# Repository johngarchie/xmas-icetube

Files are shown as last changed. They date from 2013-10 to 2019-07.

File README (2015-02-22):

##########################
## XMAS-ICETUBE PROJECT ##
##########################

Several years ago, my father gave me an Adafruit Ice Tube Clock kit as
a Christmas gift.  As an excuse to learn AVR programming, I started
playing with the firmware.  Eventually, none of the original Adafruit
code remained, and the result was a feature-rich reimplementation of
the Adafruit firmware.

Once the firmware was mature, I decided to revise the hardware design
to support many of the hacks and mods described on the Adafruit
forums.  With the help of other clock hackers, especially Phil DeGruy
and Russell Walker, the xmas-icetube hardware revision became a reality.

Today, the xmas-icetube firmware still runs on the Adafruit Ice Tube
Clock v1.1 as well as the xmas-icetube hardware revision.  For more
information on the firmware and hardware portions of this project,
please check out the firmware/README and hardware/README files.

Finally, although the xmas-icetube project is named after Christmas,
it is designed for use year-round.  The name is also a reference to
Christmas as a cultural holiday--not a religious one.  I sincerely
hope this project is compatible with all religions.

  John Archie <www.jarchie.com/email>
  April 2, 2014

###################
## USER FEEDBACK ##
###################

Below is a selection of comments posted on the Adafruit Clocks
forum.  They are listed in reverse chronological order.  And to
everyone quoted below:  Thank you all for the kind words!

  "[The xmas firmware] just worked from the beginning...
   Great documentation!"
     --MikeHg
       http://forums.adafruit.com/viewtopic.php?p=324261#p324261

  "Every mod works beautifully...  The code truly is clever...
   [John's] code is so clean that it's easy to add things."
     --rcb
       http://forums.adafruit.com/viewtopic.php?p=244224#p244224

  "This firmware is really cool. I highly recommend anyone with an
   ATmega328p lying around to program it with this firmware and use
   it instead of the one that comes with the kit."
     --motocoder
       http://forums.adafruit.com/viewtopic.php?p=243916#p243916

  "[John] has done a lot of nice work and added a lot of features.
   I can recommend his firmware as an upgrade..."
     --adafruit_support_bill,
       http://forums.adafruit.com/viewtopic.php?p=211476#p211476

  "...I LOVE your firmware, and for about 2 weeks I was still
   finding new options and features in the menu."
     --wildtang3nt
       http://forums.adafruit.com/viewtopic.php?p=204665#p204665

  "+10 for John's firmware!  Please do not let the 'xmas' name sway
   you from giving it a try. It's the most feature complete Ice-Tube
   Clock firmware to date."
     --revnull
       http://forums.adafruit.com/viewtopic.php?p=180609#p180609

##############
## FEATURES ##
##############

The xmas-icetube firmware offers the following improvements over
the official Adafruit firmware:

  - GPS synchronized timekeeping*
  - fully automatic compensation for clock drift
  - animated display transitions
  - multiple time and date formats
  - DST support (USA, EU, or manual)
  - pulsing display brightness during alarm and snooze
  - three alarm times for selectable days of the week
  - functional alarm during power outage**
  - finely adjustable alarm volume (from 0 to 10)
  - progressive alarm option (gradually increasing volume)
  - adjustable snooze duration
  - selectable alarm sound (high frequency beeps, low frequency beeps,
    high frequency three beep pulse, low frequency three beep pulse,
    Merry Christmas, Big Ben, Reveille, or For He's a Jolly Good Fellow)
  - 4-fold improvement in battery life
  - no beeping or time loss after external power failure
  - low battery warning before battery failure
  - per-digit brightness adjustment for uneven displays
  - larger range for user-configured display brightness
  - optionally disable display during specified time periods

*  An external GPS module, such as the Adafruit Ultimate GPS, is
   necessary to support GPS synchronized timekeeping.

** Without external power, the alarm sounds with loud high frequency
   beeps.  The only way to turn the alarm on or off is with the alarm
   switch.  Snooze is not supported.

The following additional features are supported on the xmas-icetube
hardware revision, but the Adafruit Ice Tube Clock v1.1 can be
modified to support any or all of the following as well:

  - automatic brightness control by ambient light
  - optionally disable display at night (when dark)
  - 25-fold improvement in battery life
  - highly accurate temperature compensated timekeeping
  - IV-18 tube driven to specifications (providing more even
    display illumination and preventing cathode poisoning)

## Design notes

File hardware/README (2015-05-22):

####################################
## XMAS-ICETUBE HARDWARE REVISION ##
####################################

The xmas-icetube hardware revision is a revision of the Adafruit Ice Tube
Clock v1.1 hardware design to support many of the hacks and mods that have
been posted to the Adafruit forums over the years.  The original circuit
board has been extensively revised, but the case and overall look of the
clock is nearly identical to the original design.

The xmas-icetube hardware revision is discussed in the following thread:

    http://forums.adafruit.com/viewtopic.php?t=43836

##############
## FEATURES ##
##############

The xmas-icetube revision has the following improvements over the original
Adafruit design.  Although all of these features are incorporated into the
xmas-icetube board, many of the links given are oriented toward modifying
the original Adafruit clock to include the corresponding features.  Those
discussions are still relevant to the xmas-icetube revision, however.

* IV-18 tube driven to specifications:  The Adafruit design runs the IV-18
  in a way that results in inconsistent illumination across the display,
  and on some tubes, the effect is quite noticeable.  The original IV-18
  drive also accelerated the process of cathode poisoning.  Driving the
  IV-18 as the designers intended ensures uniform illumination and makes
  the tube less prone to cathode poisoning.

  http://forums.adafruit.com/viewtopic.php?t=23586
  http://forums.adafruit.com/viewtopic.php?t=41811

* Automatic dimming:  A photoresistor allows automatic dimming as
  appropriate for the ambient lighting.  The Adafruit design does,
  however, have an expansion area that can also be used to this end.

  http://forums.adafruit.com/viewtopic.php?t=12932

* 25-fold reduction in sleep current:  Unless the clock is without power
  for over a year, the battery should never need replacement.

  http://forums.adafruit.com/viewtopic.php?t=36697  
  http://forums.adafruit.com/viewtopic.php?p=219736#p219736

* Temperature compensated timekeeping:  A DS18B20 temperature sensor next
  to the clock crystal allows the software to compensate for temperature-
  related timekeeping error.  When combined with software-based drift
  correction, the resulting accuracy should be comparable to a temperature
  compensated quartz oscillator.

  http://forums.adafruit.com/viewtopic.php?t=43998
  http://forums.adafruit.com/viewtopic.php?f=41&t=12720

* GPS solder points:  Through-hole solder points allow easier installation
  of an external GPS unit for time synchronization.

  http://forums.adafruit.com/viewtopic.php?t=36873
  http://learn.adafruit.com/ice-tube-clock-kit/mods

  Alternatively, these solder points may also be used for installing a
  dedicated temperature compensated crystal oscillator instead of the
  DS18B20 temperature sensor above.

  http://forums.adafruit.com/viewtopic.php?&t=14941

* Robust in-system programming:  The clock may be programmed regardless of
  whether the display and side board are installed.  I recommend powering
  the clock with external power during programming, but a programming
  jumper provides a way to force the clock into sleep mode to ensure minimal
  power consumption if powered by the programmer instead.  I recommend
  using the jumper if using the AVR Dragon programmer, as the Dragon can
  barely provide enough power for programming alone.  But the jumper is
  unnecessary for most programmers including the Adafruit USBtinyISP.

  http://forums.adafruit.com/viewtopic.php?t=41975

* Robust microcontroller environment:  The microcontroller now has a
  decoupling capacitor and 10K pull-up on the reset pin.  These
  components make the clock less sensitive to electrical noise and
  ensure reliable operation.

Finally, although the xmas-icetube firmware is compatible with *both* the
original Adafruit clock and the xmas-icetube hardware revision, the
xmas-icetube revision is not compatible with firmwares developed
specifically for the Adafruit clock.

##########################
## COLLECTING THE PARTS ##
##########################

The current versions of the xmas-icetube custom parts are:

  - main board   (Rev. D)
  - side board   (Rev. C)
  - acrylic case (Rev. A)

I ordered my circuit boards from OSH Park and have shared those uploads
in case others would like to do the same:

    http://www.oshpark.com/shared_projects/6xAVpeHb
    http://www.oshpark.com/shared_projects/PiRXWH3F

I ordered the 3mm clear acrylic parts from Ponoko and have also shared
that design:

    http://www.ponoko.com/showroom/jarchie

For those in Europe, Formulor (http://www.formulor.de/) is an alternative
source for the acrylic parts.  Formulor is a Ponoko partner and accepts
the same SVG design format.  Many thanks to Tobias Scharmann for
suggesting this service.

See the enclosed bill of materials (BOM.csv) for a complete parts list,
including manufacturers, suppliers, and part numbers.

########################
## BUILDING THE CLOCK ##
########################

For aesthetic reasons, the xmas-icetube design uses TO-92 packages for the
voltage regulators, so their ability to burn off excess voltage is limited.
The 9VDC input should stay below 10v at 120 mA to be on the safe side:  A
standard regulated switching-type 9v adapter should work fine, but I
recommend against using an older, unregulated, transformer-type wall wort.

Alternatively, the board will accommodate regulators in TO-220 packages,
even though the silkscreen shows TO-92 packages.  The holes are a bit small
for TO-220s, so it might be necessary to file down the TO-220 leads to make
them narrower, but those packages will work with a bit of extra effort.
Although, I do prefer the TO-92s, TO-220s would look okay--just a bit bulky.

When assembling the parts, I suggest building the circuit incrementally and
testing each section after it is built.  See the Eagle schematics for the
parts in each section.

1.  Solder the "5V Power Supply" parts.  Connect the 9v adaptor and verify
    that the power supply outputs 5v; disconnect and proceed.

2.  Solder the "Temperature Sensor" parts.  (It's easier to solder R9
    before inserting the microcontroller into its socket.)

3.  Solder the "Microcontroller", "ISP Header", "Battery Sensor", and
    "Speaker" parts.  Program the ATmega328P (see the firmware/README file
    for details).  When powered with the AC adaptor, the speaker should
    beep when powered for the first time.  Keep the AC adaptor connected
    for at least ten seconds after hearing the beep.

    If the speaker does not beep, ensure the programming jumper has been
    removed and that the ATmega328P is properly programmed.  If the speaker
    beeps repeatedly at 8 second intervals, the problem is most likely with
    the crystal oscillator.  If the oscillator parts and connections are
    good, cleaning excess rosin from the board with a toothbrush and
    rubbing alcohol might fix the problem, but make sure the board is
    completely dry before powering it again.

4.  Solder the "5VAC Cathode/Filament Supply" parts.  Measure the AC voltage
    between the two push-pull outputs (AC1 and AC2).  The push-pulls should
    provide high frequency, square wave, alternating current, which most
    multimeters cannot measure accurately.  Without a load, the LM317 will not
    effectively regulate voltage anyway, so multimeter accuracy does not
    matter.  So ensure that AC1 and AC2 are providing alternating current,
    but the amount of voltage measured is not important.

5.  Solder the "Tube 30-60VDC Boost Supply" parts.  Note that the joined
    leads of Q2 should be oriented toward C6.  Connect the 9v adaptor and
    verify that the boost circuit indeed provides 50-60 volts.

6.  Solder the "VFD Anode/Segment Controller" and "VFD Tube / Side PCB"
    parts.  Attach the side board to the main board, connect the 9v
    adaptor, and verify that the VFD display is functional.

7.  Solder the "Buttons and Alarm Switch" parts.  Connect the 9v adaptor
    and verify that the buttons and alarm switch function properly.

8.  Solder the "Battery Backup" parts and insert a battery, but before
    soldiering the battery case, apply a small amount of solder to the
    battery's ground connection (large square pad).  A small amount of
    solder will add height to the square pad connection and ensure a good
    connection between the battery and ground.

    Connect the 9v adaptor, set the time, disconnect the 9v adaptor for ten
    minutes, connect it again, and verify that the clock kept the correct
    time.  Because the clock is extremely power-efficient during sleep, the
    capacitors store enough charge to keep the clock running for 3-5
    minutes.  Leaving the clock unplugged for ten minutes ensures that the
    backup battery is actually in use.

9.  Solder the "Light Sensor" parts.  So the clock can accurately gauge
    ambient lighting, install the photoresistor such that it points towards
    the front of the clock and away from the tube.  Connect the 9v adaptor,
    and using a flashlight, lamp, or similar, verify that the clock
    responds to changes in ambient light.

10. Assemble the acrylic case and enjoy!

##############################
## EDITING THE DESIGN FILES ##
##############################

The board revisions can be opened and and modified with Eagle,
which is available from CadSoft:

    http://www.cadsoftusa.com/

The case revision may be viewed and modified in Inkscape:

    http://inkscape.org/

######################
## ACKNOWLEDGEMENTS ##
######################

The Adafruit Ice Tube Clock board was loosely based on the inGrid
IV-18 clock by Riad S. Wahby.  My xmas-icetube board revision is based
on the Adafruit Ice Tube Clock board by Lady Ada.

The clock case was originally designed by Amanda Wozniak (w0z), and I have
only made minor adjustments to her design.  Adafruit forum user Daygecko
also deserves credit for finding clear machine nuts and bolts from
McMaster-Carr, which give the assembled case a cleaner look.

Phil DeGruy (PhilD13) reviewed my initial design and suggested several
components; the ZVN2110A and ZVP2001A MOSFETs in particular were
especially useful for generating AC for the IV-18 filament.  Phil
also found many alternative parts for the bill of materials which cost
less than my original selections.

I also had fruitful discussions with both Phil DeGruy and Russell Walker
(Russell27), mostly  in regard to properly driving the IV-18 tube.  Phil
and Russell built their own xmas-icetube clocks and provided useful
feedback on the overall design.

Because I am inexperienced in electronics design, I must add the following
disclaimer:  Those cited in this section cannot be faulted for any bugs in
the xmas-icetube hardware revision.

#############
## LICENSE ##
#############

The xmas-icetube hardware revision may be used under the Attribution-
ShareAlike 3.0 (CC BY-SA 3.0), available from Creative Commons:

    http://creativecommons.org/licenses/by-sa/3.0/

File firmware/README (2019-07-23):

###########################
## XMAS-ICETUBE FIRMWARE ##
###########################

The xmas-icetube firmware is a complete reimplementation of the Adafruit
Ice Tube Clock firmware and runs on *both* the Adafruit Ice Tube Clock v1.1
and the xmas-icetube hardware revision.  Since most users will be using the
xmas-icetube firmware on the Adafruit Ice Tube Clock v1.1, the default
firmware configuration is set for the Adafruit clock.

The xmas-icetube firmware is discussed in the following Adafruit thread,
which is a good place to post questions and comments:

  http://forums.adafruit.com/viewtopic.php?f=41&t=34924

##############
## FEATURES ##
##############

Many of the features in the xmas-icetube firmware were first implemented in
other firmware projects; see the CREDITS file for details.  This firmware
boasts the following improvements over the official Adafruit firmware:

  - animated display transitions
  - multiple time and date formats
  - optionally pulse display during alarm and snooze
  - three alarm times for selectable days of the week
  - functional alarm during power outage
  - adjustable alarm volume (from 0 to 10)
  - progressive alarm option (gradually increasing volume)
  - selectable alarm sound (high frequency beeps, low frequency beeps,
    high frequency three beep pulse, low frequency three beep pulse,
    Merry Christmas, Big Ben, Reveille, or For He's a Jolly Good Fellow)
  - adjustable snooze duration
  - DST support (USA, EU, or manual)
  - fully automatic correction for time drift
  - time-from-GPS support*
  - temperature compensated timekeeping*
  - no beeping or time loss after external power failure
  - 4-fold or 25-fold* increase in backup battery life
  - low battery warning before battery failure
  - larger range for user-configured display brightness
  - per-digit brightness adjustment for uneven displays
  - automatic brightness control by ambient light*
  - optionally disable display during specified time periods
  - optionally disable display at night (when dark)*
  - IV-18 VFD tube driven to specifications*

*  For the Adafruit Ice Tube Clock v1.1, these hacks require hardware
   modification and support must be enabled by uncommenting macros in
   config.h.  See the HACKS AND MODS section of this file as well as the
   comments in config.h for more information.

For clock hackers, this firmware has

    (1) compatibility with the ATmega328p,
    (2) a pseudo object-oriented design,
    (3) good source code documentation, and
    (4) display/menus by finite state machine.

##################
## INSTALLATION ##
##################

Installation requires GNU Make, avr-libc, avr-gcc, and avrdude; the
instructions below presume proficiency with these tools.

This firmware requires the ATmega328p, not the ATmega168v included with
the Adafruit kit.  Due to the many features, xmas-icetube currently
requires around 30 kB of program memory, but the ATmega168v only has
16 kB.  The ATmega328p also supports Atmel picoPower features that are
used to extend battery life by 4-fold (and 25-fold with a minor hardware
modification).  The ATmega168v does not support picoPower.

Note that if your ATmega328p has an Arduino bootloader installed, it
will not work without reconfiguration.  See the TROUBLESHOOTING section
for reconfiguration instructions.

To program the chip, any avrdude-compatible ISP programmer should work,
but programming has been tested with the Adafruit USBtinyISP, the Atmel
AVR Dragon, and an Arduino programed with the ArduinoISP sketch.

Compilation and installation has been tested under

    (a) Ubuntu Linux 12.04 with the avr-gcc and avrdude packages,
    (b) MacOS 10.14.5 with CrossPack for AVR Development, and
    (c) Windows 10 with WinAVR and Cygwin's perl and bash packages.

To compile and install this firmware, first configure compile-time
options by editing the Makefile and config.h.  Then build and install the
project using the included Makefile:

(1) Edit the Configuration Variables

    First, review the macro definitions in config.h, changing definitions
    as needed to enable support for various hardware hacks.  The default
    values in config.h are suitable for the Adafruit Ice Tube Clock v1.1
    and includes support for the autodimmer and GPS mods.  For the
    xmas-icetube hardware revision, it may be more convenient to copy the
    config.h file from the hardware directory and edit that as desired:

	% cp ../hardware/config.h config.h

    Next, review the Makefile to ensure that configuration variables are
    reasonable given your hardware.  In particular, AVRISP and AVRDUDEOPT
    seem most likely to require attention.

(2) Compile the Firmware

    Build icetube_fuse.hex, icetube_flash.hex, icetube_eeprom.hex, and
    icetube_lock.hex which contain the fuse bits, program memory (flash),
    EEPROM data, and lock bits:

	% make

(3) Connect the Programmer

    Ensure the clock has an ATmega328p installed and not an ATmega168v.
    Unplug and disassemble the clock.  Remove the side PCB with VFD tube.
    Make sure that the AVR programmer will not provide power to the clock.
    (For the Adafruit USBtinyISP, this means ensuring that the
    power jumper is not installed.)  Connect the AVR programmer to the
    clock's ISP header, ensuring that pin one on the cable and the marked
    pin on the clock's ISP header match.  Finally, power the clock board
    with the external power adaptor.

(4) Install the Firmware

    Install this firmware to an ATmega328p by setting the fuse bits,
    writing the flash program, writing the EEPROM data, and setting the
    lock bits:

        % make install-all

    Alternatively, this firmware may be installed or upgraded in separate
    steps.  If you wish not to set lockbits or not to overwrite the
    EEPROM (clock settings), simply skip those commands below.

        % make install-fuse
        % make install-flash
        % make install-eeprom
        % make install-lock

(5) Verify Successful Programming (Optional, but Recommended)

    To ensure that the chip has been successfully programmed, one may
    check the chip data against what should have been installed in the
    previous step:

        % make verify-all

    One may also verify the individual sections of programmed memory.
    The following commands are equivalent to "make verify-all":

        % make verify-fuse
        % make verify-flash
        % make verify-eeprom
        % make verify-lock

#####################
## USING THE CLOCK ##
#####################

The USAGE file contains an overview of how to use the clock.

####################
## HACKS AND MODS ##
####################

Development of the various hacks and mods supported by this firmware
have been discussed extensively on the Adafruit discussion board.
Options requiring hardware changes can be enabled by uncommenting
macros in the config.h file.  Comments in the config.h describe each
optional feature in detail.

:: Automatic Display Dimming ::
http://forums.adafruit.com/viewtopic.php?f=41&t=12932
http://forums.adafruit.com/viewtopic.php?p=219736#p219736

:: Temperature Compensated Timekeeping ::
http://forums.adafruit.com/viewtopic.php?f=41&t=14941
http://forums.adafruit.com/viewtopic.php?f=41&t=43998

:: GPS Timekeeping ::
http://forums.adafruit.com/viewtopic.php?f=41&t=36873
http://learn.adafruit.com/ice-tube-clock-kit/mods
http://forums.adafruit.com/viewtopic.php?f=41&t=32660

:: Extended Battery Life ::
http://forums.adafruit.com/viewtopic.php?f=41&t=36697

:: IV-18 To-Spec Hack ::
http://forums.adafruit.com/viewtopic.php?f=41&t=41811

:: Reliably Sleeping During Power Failure ::
http://forums.adafruit.com/viewtopic.php?f=41&t=22515

:: Automatic Drift Correction ::
http://forums.adafruit.com/viewtopic.php?f=41&t=12720

:: Per-Digit Brightness Adjustment ::
http://forums.adafruit.com/viewtopic.php?f=41&t=23586

#####################
## TROUBLESHOOTING ##
#####################

:: General Troubleshooting ::

For many hardware issues, the Adafruit FAQs are quite helpful:

  http://forums.adafruit.com/viewtopic.php?f=41&t=27032
  http://learn.adafruit.com/ice-tube-clock-kit/faq

The Adafruit Clocks forums is an excellent place to ask for help:

  http://forums.adafruit.com/viewforum.php?f=41

:: Reset and Diagnostic Messages ::

After a reset, the microcontroller will examine MCUSR (microcontroller
unit status register) to determine the reason for the reset, and the
display will alternate between the restored time and a message showing
the cause of the reset.  Reset messages can be dismissed by setting
the time, as the time is usually wrong after a reset.

  "bod rset" (brown out detection reset):  The clock was reset due to
      insufficient voltage.  This usually happens when power is lost
      and the backup battery is nearly dead.

  "pin rset" (external reset):  The clock was reset by an external
      signal to the microcontroller reset pin (pin 1).  Programming
      the clock through the ISP header will trigger an external reset.
      Accidently shorting the reset pin to ground will do the same.
      This message used to read "ext rset", but the "x" looked more
      like an "H".

  "pwr rset" (power reset):  The clock started up after a complete
      power loss.  This usually happens if the clock loses external
      with without a backup battery or with a completely dead backup
      battery.

  "wdt rset" (watchdog timer reset):  During normal operation the
      clock will periodically reset the watchdog timer.  If this
      timer expires, the clock is behaving abnormally and will reset
      itself in an attempt to fix the problem.  Usually watchdog timer
      resets are caused by problems with the crystal oscillator; see
      the troubleshooting entry on crystal oscillator problems.

  "oth rset" (other reset):  If no flags were set in MCUSR to indicate
      the cause of the reset, the display will flash "oth rest".  In
      theory, this should never happen.

The clock might also flash one of the following status messages:

  "bad batt" (low battery warning):  The microcontroller checks
      the system voltage whenever the clock sleeps for more than ten
      minutes.  When the battery is low, the display will flash
      "bad batt" after the clock wakes, and the message can be
      dismissed by pressing any button.

  "gps lost" (GPS signal lost; only applies if GPS_TIMEKEEPING was
      defined in config.h):  The clock is receiving data from the GPS,
      but the GPS has been unable to acquire a signal for at least
      three minutes.

  "temp err" (temperature sensor error; only applies if
      TEMPERATURE_SENSOR was defined in config.h):  If the
      microcontroller is unable to communicate with the temperature
      sensor, the display will flash "temp err".

:: Programming Fails with an Arduino Chip ::

The Arduino Uno chip is an ATmega328p, but will not work in an Ice
Tube Clock without reconfiguration.  Arduino chips have their fuse
settings configured to use an external 16 MHz oscillator for the
system clock.  The Ice Tube Clock does not provide a suitable external
oscillator, and without an external oscillator, an Arduino chip will
not function--not even to be reconfigured.

To provide an external oscillator for reconfiguration, insert the
Arduino chip into an Arduino board.  Next, connect a programmer to the
ISP on the Arduino board and reprogram the fuses with the xmas-icetube
Makefile:  "make install-fuse".  The ATmega328p's fuse settings are
now configured to use the 8 MHz internal oscillator and can be
installed and programmed as described in the INSTALLATION section.

This method is also described in the following thread:

  http://forums.adafruit.com/viewtopic.php?p=184722#p184722

:: Other Programming Failures ::

First, ensure that the hardware is connected properly, as described in the
installation instructions above.  Second, double check the Makefile
configuration section, paying particular attention to the AVRISP and
AVRDUDEOPT macros.  Third, try programming the chip at a lower bit rate by
changing the "-B 2" option to "-B 25" in the AVRDUDEOPT macro:

  AVRDUDEOPT ?= -B 25 -P usb -c $(AVRISP) -p $(AVRMCU)

Fourth, if the chip cannot be programmed in the clock, try programming it
in a development board such as the Arduino Uno.  Finally, it's possible
that the chip is somehow damaged or bricked; usually, the simplest solution
is to simply replace the ATmega328p with a new chip and try again.

:: Dim Digits ::

The per-digit brightness control in the xmas-icetube firmware provides
one way to increase the brightness of dim digits.

With Adafruit clocks, a dim initial or final digit is almost
invariably due to insufficient filament current.  In those cases,
increasing filament current usually produces better results, but
increasing current may also introduce a brightness gradient across the
display when the menu-configured brightness level is low.  To find the
optimal current for a given clock, a good approach is to gradually
increase current across the filament until all digits have consistent
brightness at the highest menu-configured brightness setting:

First, upgrade Q3 to a FET capable of supplying more current.  One
such FET is the ZVP2110A available from Digi-Key or Mouser.**  If the
digit remains dim after upgrading Q3, replace R3 with an 11 ohm
resistor to further increase current.  And if the digit is still dim,
replace R3 with a jumper.

Note that Q3 provides power to both the filament and VFD driver chip.
Replacing R3 with a jumper or smaller resistor without first upgrading
Q3 will increase filament current, but might also result in an
insufficient logic supply voltage to the VFD driver chip.  That, in
turn, could cause faulty display operation.

**UPDATE:  For anyone who purchased an official Adafruit kit, Adafruit
           will now provide a free ZVP2110A to resolve the issue:
           http://forums.adafruit.com/viewtopic.php?p=340772#p340772

:: Flaky Segments ::

On some Adafruit clocks, display segments are flaky.  The exact symptoms
vary depending on the particular clock, but most commonly, the clock will
start normally and segments will quickly stop working until few or no
segments are active.  Also common is a display that only shows one or two
blinking segments.  But occasionally the symptoms are more bizarre such as
a display with all digits and segments continuously lit or a single digit
going blank at a certain time.  The following threads describe the flaky
segment problem and several solutions in more detail:

  http://forums.adafruit.com/viewtopic.php?f=41&t=47733
  http://forums.adafruit.com/viewtopic.php?f=41&t=49619
  http://forums.adafruit.com/viewtopic.php?f=41&t=50823
  http://forums.adafruit.com/viewtopic.php?f=41&t=51207

The flaky segment problem can be solved by replacing Q3.  Although Adafruit
will provide a free replacement for Q3, I recommend replacing Q3 with a
better FET, such as the ZVP2110A available from Digi-Key or Mouser.**

By providing additional current across the VFD filament, the ZVP2110A
will also eliminate the dim digit problem described in the previous
entry as well as extending tube life by slowing cathode poisoning.

**UPDATE:  For anyone who purchased an official Adafruit kit, Adafruit
           will now provide a free ZVP2110A to resolve the issue:
           http://forums.adafruit.com/viewtopic.php?p=340772#p340772

:: Nonfunctional Drift Correction ::

Initially the clock will not perform drift correction.  Use the clock
normally and the automatic drift correction will eventually enable
itself.  Accuracy will improve over time.

The clock estimates time drift when users change the time by more than
15 seconds.  The fastest way to enable drift correction is to (1) set
the correct time, (2) wait for the clock to drift by more than 15
seconds, and (3) set the correct time.

Occasionally setting an incorrect time will not have much effect on
drift correction, and changing time for different timezones or
daylight saving is similarly unproblematic.  The automatic drift
correction method is quite robust:

    http://forums.adafruit.com/viewtopic.php?p=178611#p178611

:: Crystal Oscillator Problems ("wdt rset") ::

The ATmega328p is more prone to oscillator issues than the ATmega168v,
and users occasionally encounter oscillator problems after upgrading.

Oscillator problems usually result in inconsistent timekeeping; the
clock may keep accurate time one day, but not on another.  When oscillator
problems are severe, the microcontroller's watchdog circuit will
detect that time is not advancing and reset the clock in an attempt to
fix the problem.  After such a reset, the clock will beep and display
"wdt rset" to indicate possible time loss due to a watchdog reset.

Fixing oscillator issues requires some trial and error, but following
the procedure below will likely fix the problem.

First, excess flux or burnt flux can cause oscillator problems.
Sometimes cleaning the board thoroughly with flux cleaner--or simply
alcohol and a toothbrush--will solve the problem.

Second, the 20 pF oscillator capacitors included in the Adafruit kit
are a bit large. Replacing C8 and C9 with with 10 pF caps will
sometimes fix the oscillator.  Even if the clock is functioning
normally, installing 10 pF caps will increase timekeeping accuracy.

Finally, replacing the crystal will sometimes resolve the issue.  The
replacement should be another 32.768 kHz crystal with a 12.5 pF load
capacitance and equivalent series resistance of 30 kOhm or less.  The
AB38T-32.768KHZ is a good choice and is available from Digi-Key or
Mouser.  When installing and soldering the crystal, gently push the
crystal through the circuit board until there is 2-3 mm of space
between the bottom of the crystal and the circuit board.  Leaving this
space prevents undue stress on the leads which could damage the
crystal; it also ensures solder will not make unwanted electrical
contact with the metallic crystal housing.

The following threads provide more information on oscillator issues
after upgrading to the ATmega328p:

    http://forums.adafruit.com/viewtopic.php?p=189366#p189366
    http://forums.adafruit.com/viewtopic.php?f=41&t=51960

#############
## LICENSE ##
#############

The xmas-icetube firmware may be used as described in the LICENSE file.

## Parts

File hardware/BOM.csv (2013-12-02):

Name | Description | Manufacturer | Manufacturer Part | Supplier | Supplier Part
main board | xmas-icetube main board (rev. d) | OSH Park |  | OSH Park
side board | xmas-icetube side board (rev. c) | OSH Park |  | OSH Park
acrylic case | xmas-icetube acrylic case (rev. a) | Ponoko |  | Ponoko
nuts (10x) | 4-40 polycarbonate hex nut | McMaster-Carr | 94905A005 | McMaster-Carr | 94905A005
bolts (8x) | 4-40 polycarbonate phillips screw | McMaster-Carr | 93140A109 | McMaster-Carr | 93140A109
9VAC | 9 v adaptor, 2.1mm jack (International) | CUI Inc | EMSA090067-P5P-SZ | Digi-Key | T1085-P5P-ND
9VAC (alt) | 9 volt adaptor, 2.1mm jack (North America) | Volgen America/Kaga Electronics USA | KTPS05-09006U | Digi-Key | 62-1167-ND
BATT | coin cell | Energizer | CR1220 | Amazon | B003CU3E2Q
display | antique vacuum florescent display | Russia (discontinued, NOS) | IV-18 | eBay/Adafruit | IV-18
9VAC' | 2.1mm power jack | CUI Inc | PJ-202A | Digi-Key | CP-202A-ND
BATT' | coin cell holder | Keystone Electronics | 3001 | Digi-Key | 3001K-ND
C1,C3,C10,C11 | 0.1uF 50v cap | Kemet | C315C104M5U5TA | Digi-Key | 399-4151-ND
C2,C7 | 47uF 35v cap | Panasonic Electronic Components | ECA-1VHG470 | Digi-Key | P5550-ND
C4 | 220uF 6.3v cap | Panasonic Electronic Components | ECA-0JHG221 | Digi-Key | P5506-ND
C5 | 0.1uF 100v cap | AVX Corporation | SR201C104KAR | Digi-Key | 478-4855-ND
C6 | 33uF 100v cap | Panasonic Electronic Components | EEU-FC2A330L | Digi-Key | P10772-ND
C8,C9 | 10pF 50v cap | Vishay BC Components | K100J15C0GF5TL2 | Digi-Key | BC1001CT-ND
D1 | 50v 1A general purpose diode | Fairchild Semiconductor | 1N4001 | Digi-Key | 1N4001FSCT-ND
D2,D4 | 20v 1A Schottky diode | Fairchild Semiconductor | 1N5817 | Digi-Key | 1N5817FSCT-ND
D3 | 60v 1A Schottky diode | ON Semiconductor | MBR160G | Digi-Key | MBR160GOS-ND
D5 | 56v 1.3W Zener diode | Vishay Semiconductor Diodes Division | 1N4758A-TR | Digi-Key | 1N4758AVSCT-ND
F1 | 250 mA resettable fuse | TE Connectivity | RXEF025-2 | Digi-Key | RXEF025CT-ND
IC1 | Microcontroller | Atmel | ATMEGA328P-PU | Digi-Key | ATMEGA328P-PU-ND
IC1' | 28 pin DIP socket | 3M | 4828-3004-CP | Digi-Key | 3M5480-ND
IC1' (alt) | 28 pin DIP socket (gold plated) | On Shore Technology Inc | SA283000 | Digi-Key | ED3026-ND
IC2 | VFD grid/segment driver | Maxim Integrated | MAX6921AQI+ | Digi-Key | MAX6921AQI+-ND
IC2' | 28 pin PLCC socket | Assmann WSW Components | A-CCS28-Z-R | Digi-Key | AE10055-ND
IC2' (alt) | 28 pin PLCC socket (gold plated) | Assmann WSW Components | A-CCS28-G-R | Digi-Key | AE10062-ND
IC3 | 5v voltage regulator | ON Semiconductor | MC78L05ABPG | Digi-Key | MC78L05ABPGOS-ND
IC4 | temperature sensor | Maxim Integrated | DS18B20+PAR | Digi-Key | DS18B20+PAR-ND
IC4 (alt) | temperature sensor | Maxim Integrated | DS18B20+ | Mouser | 700-DS18B20+
IC5 | LM317 voltage regulator | ON Semiconductor | LM317LZG | Digi-Key | LM317LZGOS-ND
ISP | 2x3 0.1inx0.1in ISP header | 3M | 961206-6404-AR | Digi-Key | 3M9459-ND
J1 | standard jumper | Sullins Connector Solutions | QPC02SXGN-RC | Digi-Key | S9337-ND
J1 (alt) | jumper with handle | Sullins Connector Solutions | NPC02SXON-RC | Digi-Key | S9341-ND
J1' | 1x2 0.1in male header | FCI | 77311-118-02LF | Digi-Key | 609-4434-ND
JP1 | 2x10 0.1inx0x.1in female header | Sullins Connector Solutions | PPPC102LFBN-RC | Digi-Key | S6106-ND
JP2 | 2x10 0.1inx0x.1in male right angle header | FCI | 68021-120HLF | Digi-Key | 609-3338-ND
L1 | 2.2mH 0.24A inductor | Murata Power Solutions Inc | 13R225C | Digi-Key | 811-2054-ND
Q1 | clock crystal oscillator | ABRACON | AB38T-32.768KHZ | Digi-Key | 535-9034-ND
Q2 | 100v N-channel MOSFET | Vishay Siliconix | IRFD110PBF | Digi-Key | IRFD110PBF-ND
Q3 | removed from design
Q4,Q6 | 100v P-channel MOSFET | Diodes Inc | ZVP2110A | Digi-Key | ZVP2110A-ND
Q5,Q7 | 100v N-channel MOSFET | Diodes Inc | ZVN2110A | Digi-Key | ZVN2110A-ND
R1 | 270k 5% resistor | Yageo | CFR-25JB-52-270K | Digi-Key | 270KQBK-ND
R2 | 100k 5% resistor | Yageo | CFR-25JB-52-100K | Digi-Key | 100KQBK-ND
R3 | removed from design
R4 | 5.6k 5% resistor | Yageo | CFR-25JB-52-5K6 | Digi-Key | 5.6KQBK-ND
R5,R10 | 10k 5% resistor | Yageo | CFR-25JB-52-10K | Digi-Key | 10KQBK-ND
R6 | photoresistor | Advanced Photonix Inc | PDV-P8001 | Digi-Key | PDV-P8001-ND
R7 | 1.00k 1% resistor | Yageo | MFR-25FBF52-1K | Digi-Key | 1.00KXBK-ND
R8 | 3.57k 1% resistor | Yageo | MFR-25FBF52-3K57 | Digi-Key | 3.57KXBK-ND
R9 | 4.7k 5% resistor | Yageo | CFR-25JB-52-4K7 | Digi-Key | 4.7KQBK-ND
S1,S2,S3 | right angle tactile switch | Panasonic Electronic Components | EVQ-PF008K | Digi-Key | P10880S-ND
SPK | piezo speaker | TDK | PS1240P02BT | Digi-Key | 445-2525-1-ND
SW1 | right angle SPDT switch | E-Switch | EG1213 | Digi-Key | EG1906-ND
SW1 (alt) | right angle SPDT switch | C&K Components | 0S102011MA1QN1 | Mouser | 611-OS102011MA1QN1

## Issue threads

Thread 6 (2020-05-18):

Using 14 character IV-27 tube and two MAX6921's

Barbouri, 2020-05-18:
I have designed the hardware using two MAX6921 VFD drivers using the DOUT and DIN connections, and would like to clock 40 bits vs the usual 20 to utilize a second MAX6921 chip. Most of the code is very well documented except clocking of the 20 bits of data.
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

johngarchie, 2020-05-18:
If I understand correctly, you'll need to expand the size of the intermediate bits array that gets sent to the maxim display chip in display.c.  Since 5x8 = 40, you'll need 5 bytes and the line declaring bits should be:   `uint8_t bits[5] = {0, 0, 0, 0, 0};`

Below are the excerpts from display.c that actually do the work of sending the data to the maxim chip:

    // bits to send MAX6921 (vfd driver chip)
    uint8_t bits[3] = {0, 0, 0};

    // <...bits[3] gets populated for transmission to driver chip...>

    // send bits to the MAX6921 (vfd driver chip)

    // Note that one system clock cycle is 1 / 8 MHz seconds or 125 ns.
    // According to the MAX6921 datasheet, the minimum pulse-width on the
    // MAX6921 CLK and LOAD pins need only be 90 ns and 55 ns,
    // respectively.  The minimum period for CLK must be at least 200 ns.
    // Therefore, no delays should be necessary in the code below.

    // Also, the bits could be sent by SPI (they are in the origional
    // Adafruit firmware), but I have found that doing so sometimes
    // results in display flicker.
    uint8_t bitflag = 0x08;
    for(int8_t bitidx=2; bitidx >= 0; --bitidx) {
        uint8_t bitbyte = bits[bitidx];

        for(; bitflag; bitflag >>= 1) {
            if(bitbyte & bitflag) {
                // output high on MAX6921 DIN pin
                PORTB |= _BV(PB3);
            } else {
                // output low on MAX6921 DIN pin
                PORTB &= ~_BV(PB3);
            }

            // pulse MAX6921 CLK pin:  shifts DIN input into
            // the 20-bit shift register on rising edge
            PORTB |=  _BV(PB5);
            PORTB &= ~_BV(PB5);
        }

        bitflag = 0x80;
    }

    // pulse MAX6921 LOAD pin:  transfers shift
    // register to latch when high; latches when low
    PORTC |=  _BV(PC0);
    PORTC &= ~_BV(PC0);

Barbouri, 2020-05-18:
That worked.
I modified one of the existing display formats to include the day of the week.
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

johngarchie, 2020-05-19:
Wow!  The other software changes you had to make to the code were non-trivial.  I recall the display code as being the most difficult part of the design....

Your hardware is also beautifully done.  Congratulations!

Closed 2020-08-13.

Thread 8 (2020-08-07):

avrdude: ERROR: address 0x4010 out of range at line 1025 of icetube_flash.hex

88gts, 2020-08-07:
I'm trying to compile fw simply for the drift correction, i am not having much luck.

With compiled firmware...
```
c:\WinAVR-20100110\bin>avrdude -c usbasp -p m168 -U flash:w:icetube_flash.hex

avrdude: warning: cannot set sck period. please check for usbasp firmware update
.
avrdude: AVR device initialized and ready to accept instructions

Reading | ################################################## | 100% 0.08s

avrdude: Device signature = 0x1e9406
avrdude: NOTE: FLASH memory has been specified, an erase cycle will be performed

         To disable this feature, specify the -D option.
avrdude: erasing chip
avrdude: warning: cannot set sck period. please check for usbasp firmware update
.
avrdude: reading input file "icetube_flash.hex"
avrdude: input file icetube_flash.hex auto detected as Intel Hex
avrdude: ERROR: address 0x4010 out of range at line 1025 of icetube_flash.hex
avrdude: write to file 'icetube_flash.hex' failed

avrdude: safemode: Fuses OK

avrdude done.  Thank you.
```

With working firmware...
```
c:\WinAVR-20100110\bin>avrdude -c usbasp -p m168 -U flash:w:iv.hex

avrdude: warning: cannot set sck period. please check for usbasp firmware update
.
avrdude: AVR device initialized and ready to accept instructions

Reading | ################################################## | 100% 0.08s

avrdude: Device signature = 0x1e9406
avrdude: NOTE: FLASH memory has been specified, an erase cycle will be performed

         To disable this feature, specify the -D option.
avrdude: erasing chip
avrdude: warning: cannot set sck period. please check for usbasp firmware update
.
avrdude: reading input file "iv.hex"
avrdude: input file iv.hex auto detected as Intel Hex
avrdude: writing flash (11142 bytes):

Writing | ################################################## | 100% 3.81s
```

Makefile
```
#ifndef CONFIG_H
#define CONFIG_H

// XMAS-ICETUBE CLOCK DESIGN
//
// The xmas-icetube revision of the Ice Tube Clock requires a few
// firmware modifications.  The XMAS_DESIGN macro below enables these
// modifications, but breaks compatibility with the Adafruit Ice Tube
// Clock v1.1.
//
// When configuring this firmware for use with the xmas-icetube
// revision, the configuration macros for the following features
// should also be enabled:  the automatic dimmer hack, the software
// temperature compensated timekeeping, and the IV-18 to-spec hack.
//
//
// #define XMAS_DESIGN

// ADAFRUIT-STYLE BUTTONS
//
// By default, the xmas-icetube firmware uses a unique button scheme
// where there is one button mapped to each basic function:
//
//   enter/exit menu:  menu button
//   next:             plus button
//   select/set:       set button
//
// With the Adafruit button scheme, the buttons used for the first two
// functions depend on context:
//
//   enter/exit menu:  menu button when time is displayed,
//                     plus button when a menu label is displayed,
//                     menu button when a setting value is displayed
//   next:             menu button when a menu label is displayed,
//                     plus button when a setting value is displayed
//   select/set:       set button
//
// In addition to being simpler, the xmas button scheme works more
// intuitively with the xmas nested configuration menus.  Even so, some
// users still prefer the Adafruit scheme, typically for reasons of
// familiarity.  The following macro enables the Adafruit button scheme.
//
//
// #define ADAFRUIT_BUTTONS

// LOW BATTERY THRESHOLD
//
// After sleeping for ten minutes, system voltage should fall to whatever
// the battery is providing.  After that time, the microcontroller will
// check the system voltage.  If system voltage is below the following
// threshold, the clock will display a low battery warning ("bad batt")
// upon waking.
//
//
#define LOW_BATTERY_VOLTAGE 2600  // millivolts

// AUTOMATIC DIMMER HACK
//
// Defining the following macro enables support for Automatic dimming.
// This hack also allows for the clock display to be disabled at night
// (when dark).
//
// In the Adafruit Ice Tube Clock v1.1, this feature requires a
// pull-up resister to be installed in R4 and a CdS photoresistor to
// be installed in CT1.  CT1 is the two expansion pins nestled among
// L1, R4, and SPK.  I suggest using a 5.6k pull-up resistor with an
// Advanced Photonix Inc PDV-P8001 photoresistor.  Note that
// photoresistors purchased from Adafruit should behave like the
// PDV-P8001 and are acceptable substitutes.
//
// The automatic dimmer hack is discussed extensively on the
// Adafruit Clocks forum:
//
//   http://forums.adafruit.com/viewtopic.php?f=41&t=12932
//   http://forums.adafruit.com/viewtopic.php?p=219736#p219736
//
//#define AUTOMATIC_DIMMER

// GPS TIMEKEEPING
//
// Defining the GPS_TIMEKEEPING macro below enables GPS detection on
// the ATmega's RX pin.  The connection speed is 9600 baud by default
// for compatibility with the Adafruit Ultimate GPS Module.  For more
// information, visit the following pages:
//
//   http://forums.adafruit.com/viewtopic.php?f=41&t=36873
//   http://www.ladyada.net/make/icetube/mods.html
//   http://forums.adafruit.com/viewtopic.php?f=41&t=32660
//
// In most cases, the clock should report an error if the GPS loses
// its fix.  But users with no GPS reception might want to disable the
// "gps lost" error message.  Those users will instead move their
// clocks to an area of good reception whenever they wish to
// syncronize the clock time with the GPS time.  To disable the GPS
// lost error message, comment out the GPS_LOST_ERROR_MSG macro below.
//
//
//#define GPS_TIMEKEEPING
//#define GPS_LOST_ERROR_MSG

// USART BAUD RATE
//
// The USART baud rate defined below is used for both the debugging
// output and GPS timekeeping.
//
//
//#define USART_BAUDRATE 9600

// TEMPERATURE COMPENSATED CRYSTAL OSCILLATOR
//
// The following macro enables support for an external 32.768 kHz
// clock source such as a Maxim DS32kHz.  This hack is discussed in
// detail on the Adafruit Clocks forum:
//
//   http://forums.adafruit.com/viewtopic.php?f=41&t=14941
//
//
// #define EXTERNAL_CLOCK

// SOFTWARE TEMPERATURE COMPENSATED TIMEKEEPING
//
// This hack requires attaching a DS18B20 OneWire temperature sensor
// to ATmega328p PC1 pin, but unfortunately the internal temperature
// of the clock is above the ambient temperature.  As a result, this
// modification is not useful for displaying room temperature.
//
// This modification is, however, useful for temperature compensated
// timekeeping, and was primarily intended for the xmas-icetube
// hardware revision.  The DS32kHz, described in the previous section,
// is a simpler solution for the Adafruit Ice Tube Clock v1.1, but the
// DS18B20 will also work in the Adafruit design.   The DS18B20 should be
// installed in parasitic mode by grounding both the VDD and GND leads.
// The DQ lead should be connected to the PC1 pin on the ATmega328p and
// to PC5 via a 4.7k pull-up resistor.
//
// The XTAL_TURNOVER_TEMP macro specifies the temperature at which the
// crystal oscillates at maximum frequency in units of deg C / 16.
// The XTAL_FREQUENCY_COEF macro specifies the parabolic temperature
// dependence of the crystal in units -ppb / (deg C)^2.  For a
// turnover temperature of 25 deg C and a frequency coefficient of
// -0.034 ppm / (deg C)^2, XTAL_TURNOVER_TEMP should be defined as 400
// (25 * 16), and XTAL_FREQUENCY_COEF should be defined as 34
// (-0.034 * -1000).
//
// The technique for software temperature compensation is described in
// the following thread:
//
//   http://forums.adafruit.com/viewtopic.php?f=41&t=43998
//
// WARNING:  If your clock is modified for the original extended
// battery hack, which shorts the ATmega328P PC1 pin to ground,
// enabling the macros below might damage your clock!  The original
// extended battery hack is described in the following thread:
//
//   http://forums.adafruit.com/viewtopic.php?t=36697
//
//
// #define TEMPERATURE_SENSOR
// #define XTAL_TURNOVER_TEMP  400  // deg C / 16
// #define XTAL_FREQUENCY_COEF 34   // -ppb / (deg C)^2

// BIRTHDAY ALARM
//
// If BDAY_ALARM_MONTH and BDAY_ALARM_DAY are defined, the alarm
// sound on that day will always be "For He's a Jolly Good Fellow,"
// regardless of the alarm sound set in the menus.
//
//
// #define BDAY_ALARM_MONTH 5
// #define BDAY_ALARM_DAY   1
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
johngarchie, 2020-08-08:
The xmas-icetube firmware too large to fit on the ATmega168, so you'll need to swap that chip for an ATmega328p.  The "p" is also necessary to get the power saving features to extend backup battery life.

The error you're getting is happening just after the 16 kB mark, because the flash memory on the 168 is only 16 kB (0x4010 = 16400 = 16.02 kB).  This error happens when loading code that is too large to fit in the flash memory.

Also, I would suggest installing the firmware with the Makefile (via "make install-all") to ensure that the eeprom, flash, and all fuses are all setup correctly.  You'll need to change the "AVRISP ?= usbtiny" line in the Makefile to reflect your programmer.

Check out the firmware/README file for more details.

Good luck!

88gts, 2020-08-10:
Thanks for the feedback, I went and picked up a couple 328ps, but now having trouble connecting.  i was able to issue acrdude -c usbasp -p m168 to connect/flash the 168 chip.  With the same programmer and tools, I cant connect to the 328p using avrdude -c usbasp -p m328p (also trying via make-install all).  is there an extra initialization step i am missing? swapping back to the 168 does work so i dont think its an issue with this programmer.

```
avrdude -B 4 -P usb -c usbasp -p atmega328p -u -U lfuse:w:0x62:m -u -U hfuse:w:0xD1:m -u -U efuse:w:0x06:m -U flash:w:icetube_flash.hex:i -U eeprom:w:icetube_eeprom.hex:i -U lock:w:0x2B:m

avrdude: set SCK frequency to 187500 Hz
avrdude: warning: cannot set sck period. please check for usbasp firmware update.
avrdude: error: program enable: target doesn't answer. 1
avrdude: initialization failed, rc=-1
         Double check connections and try again, or use -F to override
         this check.

avrdude done.  Thank you.

make: [Makefile:109: install-all] Error 1 (ignored)
```

johngarchie, 2020-08-11:
Sounds like progress, at least.  The `initialization failed, rc=-1` error means that there is failed communication between the programmer and the chip.  Have you tried the troubleshooting suggestions in the [firmware/README](https://github.com/johngarchie/xmas-icetube/tree/master/firmware#readme) file?

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

88gts, 2020-08-11:
Yes, I tried changing the -B value with no luck, I'm going to order an Arduino board and see.  Will get back to you, thanks!

johngarchie, 2020-08-11:
The Arduino board will help if these are pre-programmed Arduino chips.  They would have been marketed as Arduino chips, though.  For example, Adafruit calls them "Arduino bootloader-programmed chip (Atmega328P)".

With an Arduino chip, it is also possible to breadboard the clock pins to a 16 MHz crystal oscillator, connect an ISP header, and use the bread boarded setup to reprogram the chips to work in the clock.

As far as the "-B 25" option, I had one user report having to change the 25 to a much larger value.  I can't remember what exactly he used, but if clock speed is the problem any value big enough will work.

88gts, 2020-08-12:
works with the arduino board! thanks for the guidance, flashed and rocking! lets hope this resolves the clock drift :)

johngarchie, 2020-08-13:
Congratulations!  Well done.

Closed 2020-08-13.

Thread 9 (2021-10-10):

GPS $GNRMC is not used

XiteHosting, 2021-10-10:
Hi,
I've bought this GPS online "BN-220".
After trying the Adafruit GPS firmware (which didn't work since they use 4800bps and the gps uses 9600bps)
Trying your firmware and another one I found on the internet, and never getting any positive outcomes.

I linked the GPS to a raspberry pi to read what is coming in.
This is an excerpt of the data:
(44) $GNGSA,A,3,,,,,,,,,,,,,13.29,6.52,11.58*19
(68) $GPGSV,3,1,12,02,42,253,13,04,14,075,15,05,22,303,,06,27,202,26*7F
(66) $GPGSV,3,2,12,07,66,131,08,09,50,074,,11,46,240,25,13,07,253,*7A
(64) $GPGSV,3,3,12,16,15,040,,20,54,294,,29,08,317,,30,44,185,26*7C
(18) $GLGSV,1,1,00*65
(52) $GNGLL,5104.87634,N,00342.00064,E,140052.00,A,A*7C
(68) $GNRMC,140053.00,A,5104.87502,N,00341.99862,E,1.638,,101021,,,A*60
(35) $GNVTG,,T,,M,1.638,N,3.033,K,A*32
(74) $GNGGA,140053.00,5104.87502,N,00341.99862,E,1,04,6.51,-4.6,M,46.0,M,,*68
(52) $GNGSA,A,3,02,06,07,30,,,,,,,,,13.27,6.51,11.56*1A
(44) $GNGSA,A,3,,,,,,,,,,,,,13.27,6.51,11.56*1A
(68) $GPGSV,3,1,12,02,42,253,12,04,14,075,15,05,22,303,,06,27,202,26*7E
(66) $GPGSV,3,2,12,07,66,131,12,09,50,074,,11,46,240,25,13,07,253,*71
(64) $GPGSV,3,3,12,16,15,040,,20,54,294,,29,08,317,,30,44,185,26*7C
(18) $GLGSV,1,1,00*65
(52) $GNGLL,5104.87502,N,00341.99862,E,140053.00,A,A*76

Looking in your (and the other guy's) code, I see you search for "GPRMC" and not for "GNRMC" like mine is showing.
I would think this is GPS vs Glonass?

I've changed this to GNRMC and my clock is working fine. I also tried changing it to RMC, so it could work for everyone, but that doesn't seem to work. Probably because you don't search for the string in the GPS output, but compare the first x characters.

I have no idea how to fix this in C code :-) But maybe someone else does.

regards,
Stijn

johngarchie, 2021-10-12:
Congratulations on getting the firmware to work with your GPS!

When I wrote the code, the Adafruit Ultimate GPS was what most people were using with the Adafruit Ice Tube Clock, and the Ultimate GPS used "GPRMC" to report time.  Other users tried my firmware with other GPS units and had luck, so I--perhaps naively--assumed that this is how most GPS units behaved.

My firmware is also very picky about only setting time from what looks like a valid RMC message and even verifies the checksum.  At least one clock user was broadcasting the NMEA data from his GPS over radio to his clock and needed corrupted RMC records to be discarded.  For better or worse, this is why the firmware does not just search for the "RMC" string, but instead processes the entire RMC message.

Unfortunately, I'm not able to easily test modifications to the firmware at the moment, but you might try changing the source to accept any the two digit talker code as valid.  This could probably be done by finding the following lines in gps.c:

              const char *gprmc_str = "GPRMC";
              if(gps.idx >= 5 || c != gprmc_str[gps.idx]) {

And changing them to something like

              const char *rmc_str = "**RMC";
              if(gps.idx >= 5 || (gps.idx >= 2 && c != rmc_str[gps.idx])) {

(I haven't tested this however...)

Hope that helps!

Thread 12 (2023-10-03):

NTP to Icetube clock using any ESP8266 or ESP32

BaltasarParreira, 2023-10-03:
Regarding my post https://github.com/johngarchie/xmas-icetube/issues/11 I had an idea that I'm implementing right now.

Using one of this boards (ESP8266 or ESP32) I can connect to the internet (NTP and geolocalization by IP) and get all the necessary data for creating the same NMEA GPS sentences (spoof or fake them) and send them thought the serial port pins of the ESP connected to the GPS pins on the clock board.

Like this will have the same synchronized time as the clock will think that has a GPS board is connected to it.   ; )

As soon I have all working I'll put the MOD and code here.

BaltasarParreira, 2023-10-03:
Hi everyone, my final code is ready and working 100% so here it is for anyone who wants to create this mod.

`/**
 * Icetube Clock NTP to GPS converter using ESP8266 or ESP32
 * V1.1 by BaltasarParreira
 * Using parts/code from NMEA CRC generator by ninetreesdesign David (https://github.com/ninetreesdesign/CRC-Checksum-Function/blob/master/ds_CRC_function.ino)
 */
//#include <Arduino.h>
//#include <ESP8266WiFi.h>

#include <WiFiManager.h> // https://github.com/tzapu/WiFiManager
#include <NTPClient.h>
#include <WiFiUdp.h>

#define DEBUG
#include "IPGeolocation.h"

const long utcOffsetInSeconds = 0; //3600;

char daysOfTheWeek[7][12] = {"Sunday", "Monday", "Tuesday", "Wednesday", "Thursday", "Friday", "Saturday"};

// Define NTP Client to get time
WiFiUDP ntpUDP;
NTPClient timeClient(ntpUDP, "pool.ntp.org", utcOffsetInSeconds);

#define TRIGGER_PIN 0

// wifimanager can run in a blocking mode or a non blocking mode
// Be sure to know how to process loops with no delay() if using non blocking
bool wm_nonblocking = false; // change to true to use non blocking

WiFiManager wm; // global wm instance
WiFiManagerParameter custom_field; // global param ( for non blocking w params )

// Function to generate the NMEA 8-bit CRC
////////////////////////////////////////////////////
// - A message is built and placed into a buffer string
// - The checksum is computed, and formatted to two chars
// - The full string is printed to the IDE monitor
//   EX1:  $test*   crc = 16
//   EX2:  $GPRMC,023405.00,A,1827.23072,N,06958.07877,W,1.631,33.83,230613,,,A*  crc = 42

// 2017-10-19 streamlined this to be a clearer example, posted to github

const byte buff_len = 90;
char CRCbuffer[buff_len];

// create pre-defined strings to control flexible output formatting
String sp = " ";
String delim = ",";
String splat = "*";
String msg = "";

String latitude;
String longitude;
////////////////////////////////////////////////////

void setup() {
  WiFi.mode(WIFI_STA); // explicitly set mode, esp defaults to STA+AP
  Serial.begin(115200);
  Serial1.begin(9600);
  Serial.setDebugOutput(false);
  delay(3000);
  Serial.println("\n Starting");

  pinMode(TRIGGER_PIN, INPUT);

  // wm.resetSettings(); // wipe settings

  if(wm_nonblocking) wm.setConfigPortalBlocking(false);

  // add a custom input field
  int customFieldLength = 40;

  // new (&custom_field) WiFiManagerParameter("customfieldid", "Custom Field Label", "Custom Field Value", customFieldLength,"placeholder=\"Custom Field Placeholder\"");

  // test custom html input type(checkbox)
  // new (&custom_field) WiFiManagerParameter("customfieldid", "Custom Field Label", "Custom Field Value", customFieldLength,"placeholder=\"Custom Field Placeholder\" type=\"checkbox\""); // custom html type

  // test custom html(radio)
  const char* custom_radio_str = "<br/><label for='customfieldid'>Custom Field Label</label><input type='radio' name='customfieldid' value='1' checked> One<br><input type='radio' name='customfieldid' value='2'> Two<br><input type='radio' name='customfieldid' value='3'> Three";
  new (&custom_field) WiFiManagerParameter(custom_radio_str); // custom html input

  wm.addParameter(&custom_field);
  wm.setSaveParamsCallback(saveParamCallback);

  // custom menu via array or vector
  //
  // menu tokens, "wifi","wifinoscan","info","param","close","sep","erase","restart","exit" (sep is seperator) (if param is in menu, params will not show up in wifi page!)
  // const char* menu[] = {"wifi","info","param","sep","restart","exit"};
  // wm.setMenu(menu,6);
  std::vector<const char *> menu = {"wifi","info","param","sep","restart","exit"};
  wm.setMenu(menu);

  // set dark theme
  wm.setClass("invert");

  //set static ip
  // wm.setSTAStaticIPConfig(IPAddress(10,0,1,99), IPAddress(10,0,1,1), IPAddress(255,255,255,0)); // set static ip,gw,sn
  // wm.setShowStaticFields(true); // force show static ip fields
  // wm.setShowDnsFields(true);    // force show dns field always

  // wm.setConnectTimeout(20); // how long to try to connect for before continuing
  wm.setConfigPortalTimeout(30); // auto close configportal after n seconds
  // wm.setCaptivePortalEnable(false); // disable captive portal redirection
  // wm.setAPClientCheck(true); // avoid timeout if client connected to softap

  // wifi scan settings
  // wm.setRemoveDuplicateAPs(false); // do not remove duplicate ap names (true)
  // wm.setMinimumSignalQuality(20);  // set min RSSI (percentage) to show in scans, null = 8%
  // wm.setShowInfoErase(false);      // do not show erase button on info page
  // wm.setScanDispPerc(true);       // show RSSI as percentage not graph icons

  // wm.setBreakAfterConfig(true);   // always exit configportal even if wifi save fails

  bool res;
  // res = wm.autoConnect(); // auto generated AP name from chipid
   res = wm.autoConnect("IcetubeClockAP"); // anonymous ap
  //res = wm.autoConnect("AutoConnectAP","password"); // password protected ap

  if(!res) {
    Serial.println("Failed to connect or hit timeout");
    // ESP.restart();
  }
  else {
    //if you get here you have connected to the WiFi
    Serial.println("Connected...yeey :)");
  }

  // Start NTP
  ////////////////////////////////////////////////////
  timeClient.begin();
  ////////////////////////////////////////////////////

  // Start IP Geolocalization
  ////////////////////////////////////////////////////
  String Key = "<Go to abstractapi.com and register a free account !!!>";

  IPGeolocation location(Key,"ABSTRACT");
  IPGeo IPG;
  location.updateStatus(&IPG);
  // Debug JSON reply
  Serial.println(location.getResponse());
  Serial.println(IPG.city);
  Serial.println(IPG.country);
  Serial.println(IPG.country_code);
  Serial.println(IPG.tz);
  Serial.println(IPG.offset);
  Serial.println(IPG.is_dst);
  Serial.println(IPG.latitude,4);
  Serial.println(IPG.longitude,4);
  ////////////////////////////////////////////////////

  // Build Latitude and Longitude values
  ////////////////////////////////////////////////////
  String lat_tmp = String(IPG.latitude,4);
  String long_tmp = String(IPG.longitude,4);

  String lat_ns = "";
  if (lat_tmp.startsWith("-"))
    lat_ns = ",S";
  else
    lat_ns = ",N";
  lat_tmp.replace("-", "");

  String long_ew = "";
  if (long_tmp.startsWith("-"))
    long_ew = ",W";
  else
    long_ew = ",E";
  long_tmp.replace("-", "");

  int lat_ind = lat_tmp.indexOf('.');  //finds location of "."
  String lat_degrees = lat_tmp.substring(0, lat_ind);  //captures first data String
  String lat_decimaldegrees = lat_tmp.substring(lat_ind);  //captures second data String
  float l_decimaldegrees = lat_decimaldegrees.toFloat()*60;

  int long_ind = long_tmp.indexOf('.');  //finds location of "."
  String long_degrees = long_tmp.substring(0, long_ind);  //captures first data String
  String long_decimaldegrees = long_tmp.substring(long_ind);  //captures second data String
  float lo_decimaldegrees = long_decimaldegrees.toFloat()*60;

  char f_lat_degrees[3];
  char f_long_degrees[4];
  sprintf(f_lat_degrees, "%02s", lat_degrees);
  sprintf(f_long_degrees, "%03s", long_degrees);

  String f_l_decimaldegrees = String(l_decimaldegrees, 4);
  String f_lo_decimaldegrees = String(lo_decimaldegrees, 4);
  if (f_l_decimaldegrees.length() == 6)
    f_l_decimaldegrees = "0" + f_l_decimaldegrees;
  if (f_lo_decimaldegrees.length() == 6)
    f_lo_decimaldegrees = "0" + f_lo_decimaldegrees;

  latitude = f_lat_degrees + f_l_decimaldegrees + lat_ns;
  longitude = f_long_degrees + f_lo_decimaldegrees + long_ew;

  // Debug Latitude and Longitude values
  /*
  Serial.println(f_lat_degrees);
  Serial.println(f_l_decimaldegrees);
  Serial.println(latitude);

  Serial.println(f_long_degrees);
  Serial.println(f_lo_decimaldegrees);
  Serial.println(longitude);
  */
  ////////////////////////////////////////////////////
}

void checkButton(){
  // check for button press
  if ( digitalRead(TRIGGER_PIN) == LOW ) {
    // poor mans debounce/press-hold, code not ideal for production
    delay(50);
    if( digitalRead(TRIGGER_PIN) == LOW ){
      Serial.println("Button Pressed");
      // still holding button for 3000 ms, reset settings, code not ideaa for production
      delay(3000); // reset delay hold
      if( digitalRead(TRIGGER_PIN) == LOW ){
        Serial.println("Button Held");
        Serial.println("Erasing Config, restarting");
        wm.resetSettings();
        ESP.restart();
      }

      // start portal w delay
      Serial.println("Starting config portal");
      wm.setConfigPortalTimeout(120);

      if (!wm.startConfigPortal("OnDemandAP","password")) {
        Serial.println("failed to connect or hit timeout");
        delay(3000);
        // ESP.restart();
      } else {
        //if you get here you have connected to the WiFi
        Serial.println("connected...yeey :)");
      }
    }
  }
}

String getParam(String name){
  //read parameter from server, for customhmtl input
  String value;
  if(wm.server->hasArg(name)) {
    value = wm.server->arg(name);
  }
  return value;
}

void saveParamCallback(){
  Serial.println("[CALLBACK] saveParamCallback fired");
  Serial.println("PARAM customfieldid = " + getParam("customfieldid"));
}

void loop() {
  if(wm_nonblocking) wm.process(); // avoid delays() in loop when non-blocking and other long running code
  checkButton();

  // put your main code here, to run repeatedly:
  timeClient.update();

  time_t epochTime = timeClient.getEpochTime();

 //Get a time structure
  struct tm *ptm = gmtime ((time_t *)&epochTime);

  int monthDay = ptm->tm_mday;
  int currentMonth = ptm->tm_mon+1;
  int currentYear = ptm->tm_year+1900;

/*
// NMEA message examples
char gps[7][80] = {
    "$GPGGA,220112.00,2118.99192,N,15751.19869,W,2,10,0.83,38.7,M,-20.2,M,,0000*4B",
    "$GPGSA,A,3,30,28,19,42,03,06,50,02,07,09,,,1.63,0.83,1.40*03",
    "$GPGSV,4,1,15,02,33,254,30,03,11,047,11,05,08,207,17,06,56,315,23*77",
    "$GPGSV,4,2,15,07,14,158,19,09,10,124,10,13,05,238,,17,25,007,*7B",
    "$GPGSV,4,3,15,19,23,338,16,28,60,062,40,30,40,180,28,35,38,093,39*79",
    "$GPRMC,220112.00,A,2118.99202,N,15751.19867,W,0.025,,"+timeClient.getDay()+",,,D*77",
    "$GPVTG,,T,,M,0.025,N,0.046,K,D*23"
};
*/

String time = timeClient.getFormattedTime();
String finaltime = time;
finaltime.replace(":","");
char date[9];
sprintf(date, "%02hhu%02hhu%02hhu", monthDay, currentMonth, currentYear%100);

// Build NMEA message
  String cmd = "$GPRMC";    // a command name
  msg = cmd + delim + finaltime + ".00,A," + latitude + delim + longitude +",0.0,038.1" + delim + date + ",,,A" + splat;
  outputMsg(msg); // print the entire message string, and append the CRC

  delay(1000);
}
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
BaltasarParreira, 2023-10-03:
And here a video showing everything working.

[NTP to GPS for Icetube clock using any ESP8266 or ESP32](https://youtu.be/ZumIusNLJv8)

You will see that at first the clock has some wrong time and date, so as soon the ESP starts sending the NMEA messages (blue led blinking) the clock auto adjusts to correct time and date for the DST and region settings I have.

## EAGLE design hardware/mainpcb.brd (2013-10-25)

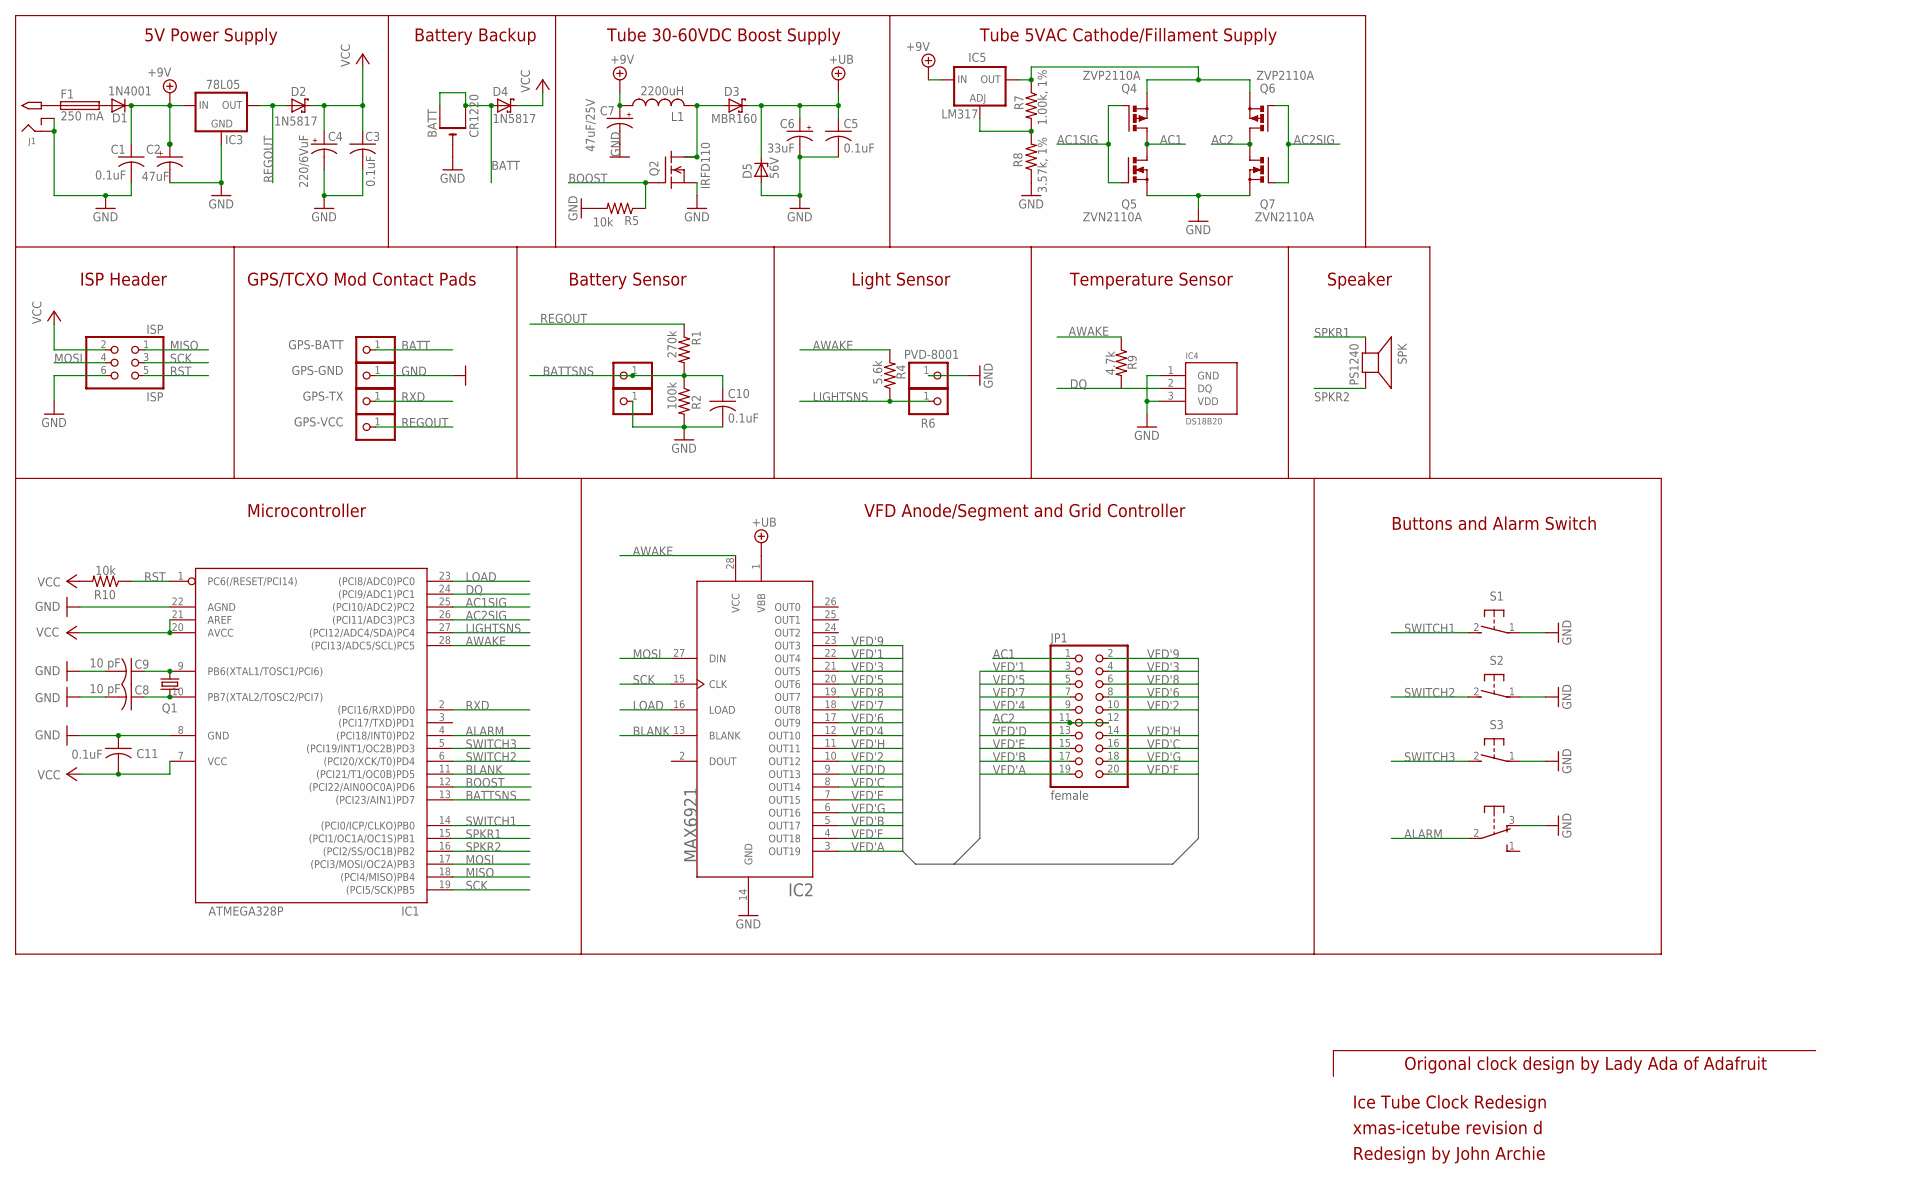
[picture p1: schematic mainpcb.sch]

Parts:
BATT: CR1220; CR1220-THM
C1, C3, C11: 0.1uF; C025-025X050
C2: 47uF; E2,5-6
C4: 220/6VuF; E2,5-6
C5, C10: 0.1uF; C025-024X044
C6: 33uF; E3,5-8
C7: 47uF/25V; E2,5-6
C8, C9: 10 pF; C025-024X044
CT2, CT3: PINHD-1X1; 1X01
D1: 1N4001; DO41-10
D2, D4: 1N5817; DO41-10
D3: MBR160; DO41-10
D5: 56V; DO41Z10
F1: 250 mA; TE5
GPS-BATT: PINHD-1X1; 1X01
GPS-GND: PINHD-1X1; 1X01
GPS-TX: PINHD-1X1; 1X01
GPS-VCC: PINHD-1X1; 1X01
IC1: ATMEGA328P; DIL28/3
IC2: MAX6921; PLCC-S28
IC3: 78L05; TO92-LINE
IC4: DS18B20; TO92
IC5: LM317; TO92-LINE
ISP: ISP; 2X03
J1: 2.1MMJACK; PJ-102A
JP1: female; 2X10
L1: 2200uH; 6000
Q1: 32.768 khz; TC26V
Q2: IRFD110; DIL04
Q4, Q6: ZVP2110A; TO92-FLAT
Q5, Q7: ZVN2110A; TO92-FLAT
R1: 270k; 0207/10
R2: 100k; 0207/10
R4: 5.6k; 0207/5V
R5, R10: 10k; 0207/5V
R6: PVD-8001; 1X01
R6.1: PINHD-1X1; 1X01
R7: 1.00k, 1%; 0207/5V
R8: 3.57k, 1%; 0207/5V
R9: 4.7k; 0207/10
S1, S2, S3: 31-XX; B3F-31XX
SPK: PS1240; PS12
SW1: OS102011MA1Q

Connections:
+9V: C1.1, C2.+, C7.+, D1.C, IC3.3 (IN), IC5.3 (IN), L1.1
+UB: C5.1, C6.+, D3.C, D5.C, IC2.1 (VBB)
AC1: JP1.1, Q4.3 (D), Q5.3 (D)
AC1SIG: IC1.25 ((PCI10/ADC2)PC2), Q4.2 (G), Q5.2 (G)
AC2: JP1.11, JP1.12, Q6.3 (D), Q7.3 (D)
AC2SIG: IC1.26 ((PCI11/ADC3)PC3), Q6.2 (G), Q7.2 (G)
ALARM: IC1.4 ((PCI18/INT0)PD2), SW1.2
AWAKE: IC1.28 ((PCI13/ADC5/SCL)PC5), IC2.28 (VCC), R4.2, R9.1
BATT: BATT.+1 (+), BATT.+2 (+1), D4.A, GPS-BATT.1
BATTSNS: C10.1, CT2.1, IC1.13 ((PCI23/AIN1)PD7), R1.2, R2.1
BLANK: IC1.11 ((PCI21/T1/OC0B)PD5), IC2.13 (BLANK)
BOOST: IC1.12 ((PCI22/AIN0OC0A)PD6), Q2.3 (G), R5.1
DQ: IC1.24 ((PCI9/ADC1)PC1), IC4.2 (DQ), R9.2
GND: BATT.-, C1.2, C2.-, C3.2, C4.-, C5.2, C6.-, C7.-, C8.2, C9.2, C10.2, C11.1, CT3.1, D5.A, GPS-GND.1, IC1.8 (GND), IC1.22 (AGND), IC2.14 (GND), IC3.2 (GND), IC4.1 (GND), IC4.3 (VDD), ISP.6, J1.RING, J1.RING_SW, Q2.4 (S), Q5.1 (S), Q7.1 (S), R2.2, R5.2, R6.1, R8.1, S1.1, S2.1, S3.1, SW1.3 (O)
LIGHTSNS: IC1.27 ((PCI12/ADC4/SDA)PC4), R4.1, R6.1.1
LOAD: IC1.23 ((PCI8/ADC0)PC0), IC2.16 (LOAD)
MISO: IC1.18 ((PCI4/MISO)PB4), ISP.1
MOSI: IC1.17 ((PCI3/MOSI/OC2A)PB3), IC2.27 (DIN), ISP.4
unnamed: C9.1, IC1.9 (PB6(XTAL1/TOSC1/PCI6)), Q1.2
unnamed: D3.A, L1.2, Q2.1 (D), Q2.2 (D1)
unnamed: C8.1, IC1.10 (PB7(XTAL2/TOSC2/PCI7)), Q1.1
unnamed: F1.1, J1.TIP
unnamed: D1.A, F1.2
unnamed: IC5.1 (ADJ), R7.2, R8.2
unnamed: IC5.2 (OUT), Q4.1 (S), Q6.1 (S), R7.1
REGOUT: D2.A, GPS-VCC.1, IC3.1 (OUT), R1.1
RST: IC1.1 (PC6(/RESET/PCI14)), ISP.5, R10.1
RXD: GPS-TX.1, IC1.2 ((PCI16/RXD)PD0)
SCK: IC1.19 ((PCI5/SCK)PB5), IC2.15 (CLK), ISP.3
SPKR1: IC1.15 ((PCI1/OC1A/OC1S)PB1), SPK.P$1 (+)
SPKR2: IC1.16 ((PCI2/SS/OC1B)PB2), SPK.P$2 (-)
SWITCH1: IC1.14 ((PCI0/ICP/CLKO)PB0), S1.2 (S)
SWITCH2: IC1.6 ((PCI20/XCK/T0)PD4), S2.2 (S)
SWITCH3: IC1.5 ((PCI19/INT1/OC2B)PD3), S3.2 (S)
VCC: C3.1, C4.+, C11.2, D2.C, D4.C, IC1.7 (VCC), IC1.20 (AVCC), IC1.21 (AREF), ISP.2, R10.2
VFD'1: IC2.22 (OUT4), JP1.3
VFD'2: IC2.10 (OUT12), JP1.10
VFD'3: IC2.21 (OUT5), JP1.4
VFD'4: IC2.12 (OUT10), JP1.9
VFD'5: IC2.20 (OUT6), JP1.5
VFD'6: IC2.17 (OUT9), JP1.8
VFD'7: IC2.18 (OUT8), JP1.7
VFD'8: IC2.19 (OUT7), JP1.6
VFD'9: IC2.23 (OUT3), JP1.2
VFD'A: IC2.3 (OUT19), JP1.19
VFD'B: IC2.5 (OUT17), JP1.17
VFD'C: IC2.8 (OUT14), JP1.16
VFD'D: IC2.9 (OUT13), JP1.13
VFD'E: IC2.7 (OUT15), JP1.15
VFD'F: IC2.4 (OUT18), JP1.20
VFD'G: IC2.6 (OUT16), JP1.18
VFD'H: IC2.11 (OUT11), JP1.14

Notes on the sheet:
5V Power Supply
GPS/TCXO Mod Contact Pads
Tube 30-60VDC Boost Supply
Ice Tube Clock Redesign
xmas-icetube revision d
Redesign by John Archie
Tube 5VAC Cathode/Fillament Supply
ISP Header
Battery Backup
Microcontroller
VFD Anode/Segment and Grid Controller
Buttons and Alarm Switch
Battery Sensor
Light Sensor
Temperature Sensor
Speaker
Origonal clock design by Lady Ada of Adafruit

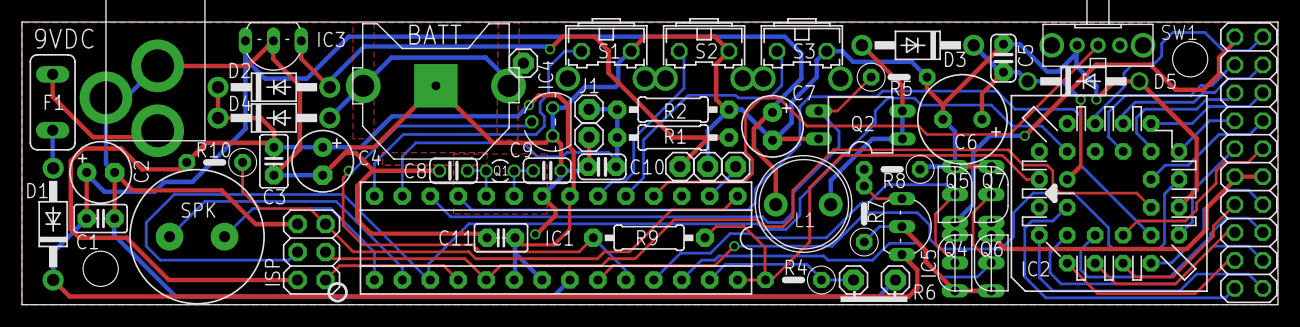
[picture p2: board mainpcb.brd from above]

Board: 2 copper layers, 114.2 x 25.7 mm, 54 parts (0 on the bottom side), 52 nets.

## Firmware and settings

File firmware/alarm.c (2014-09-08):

// alarm.c  --  alarm functionality
//
//    PD2               alarm switch
//


#include <avr/io.h>           // for using avr register names
#include <avr/pgmspace.h>     // for accessing data in program memory
#include <avr/eeprom.h>       // for accessing data in eeprom
#include <avr/power.h>        // for enabling/disabling microcontroller modules
#include <util/delay_basic.h> // for the _delay_loop_1() macro


#include "alarm.h"
#include "piezo.h"   // for sounding the alarm
#include "time.h"    // alarm must sound at appropriate time
#include "system.h"  // alarm behavior depends on power source
#include "mode.h"    // mode updated on alarm state changes
#include "usart.h"   // for debugging output
#include "display.h" // for ensuring display is enabled


// extern'ed alarm data
volatile alarm_t alarm;


// default alarm times
uint8_t ee_alarm_hours[ALARM_COUNT] EEMEM = {
    [0 ... ALARM_COUNT - 1] = ALARM_DEFAULT_HOUR
};

uint8_t ee_alarm_minutes[ALARM_COUNT] EEMEM = {
    [0 ... ALARM_COUNT - 1] = ALARM_DEFAULT_MINUTE
};

uint8_t ee_alarm_days[ALARM_COUNT] EEMEM = {
    [0 ... ALARM_COUNT - 1] = ALARM_DEFAULT_DAYS
};

// volume range, and snooze timeout
uint8_t ee_alarm_status      EEMEM = ALARM_SOUNDING_PULSE
				     | ALARM_SNOOZING_PULSE;
uint8_t ee_alarm_snooze_time EEMEM = ALARM_DEFAULT_SNOOZE_TIME;
uint8_t ee_alarm_volume_min  EEMEM = ALARM_DEFAULT_VOLUME_MIN;
uint8_t ee_alarm_volume_max  EEMEM = ALARM_DEFAULT_VOLUME_MAX;
uint8_t ee_alarm_ramp_time   EEMEM = ALARM_DEFAULT_RAMP_TIME;


// initialize alarm after system reset
void alarm_init(void) {
    // load alarms
    for(uint8_t i = 0; i < ALARM_COUNT; ++i) alarm_loadalarm(i);

    // load alarm configuration and ensure reasonable values
    alarm.status       = eeprom_read_byte(&ee_alarm_status)
			 & ALARM_SETTINGS_MASK;
    alarm.snooze_time  = eeprom_read_byte(&ee_alarm_snooze_time) % 31;
    alarm.ramp_time    = eeprom_read_byte(&ee_alarm_ramp_time )  % 61;
    alarm.volume_max   = eeprom_read_byte(&ee_alarm_volume_max)  % 11;
    alarm.volume_min   = eeprom_read_byte(&ee_alarm_volume_min);

    // convert snooze time from minutes to seconds
    alarm.snooze_time *= 60;

    // ensure alarm.volume_min is in the correct range
    if(alarm.volume_min > alarm.volume_max) {
	alarm.volume_min = alarm.volume_max;
    }

    piezo_setvolume((alarm.volume_min + alarm.volume_max) >> 1, 0);

    // prevents divide-by-zero error later on
    if(!alarm.ramp_time) alarm.ramp_time = 1;

    // calculate time.ramp_int
    alarm_newramp();

    // configure pins for low-power mode
    alarm_sleep();
}


// initialize alarm after sleep
void alarm_wake(void) {
    // configure alarm switch pin
    DDRD  &= ~_BV(PD2); // set as input pin
    PORTD |=  _BV(PD2); // enable pull-up resistor

    // give system time to update PIND
    _delay_loop_1(2);

    // set initial alarm status from alarm switch
    if(PIND & _BV(PD2)) {
	alarm.status |= ALARM_SET;
    } else {
	if(alarm.status & ALARM_SOUNDING) piezo_alarm_stop();
	alarm.status &= ~ALARM_SET & ~ALARM_SOUNDING & ~ALARM_SNOOZE;
	display.status &= ~DISPLAY_PULSING;
	display_autodim();
    }

    if(alarm.status & ALARM_SOUNDING) {
	// lower volume which may be raised above
	// volume_max during sleep mode
	alarm.volume = alarm.volume_max;
	piezo_setvolume(alarm.volume, 0);
    }
}


// prepare alarm for sleep
void alarm_sleep(void) {
    // clamp alarm switch pin to ground
    PORTD &= ~_BV(PD2); // disable pull-up resistor
    DDRD  |=  _BV(PD2); // set as ouput, clamped to ground

    if(alarm.status & ALARM_SOUNDING) {
	// disable progressive alarm to save power
	alarm.volume = alarm.volume_max;

	// finally set the volume
	piezo_setvolume(alarm.volume, 0);
    }
}


// sound alarm at the correct time if alarm is set
void alarm_tick(void) {
    // will be set to TRUE if alarm should be triggered
    uint8_t is_alarm_trigger = FALSE;
    
    // check if alarm time is now
    for(uint8_t i = 0; i < ALARM_COUNT; ++i) {
	if((alarm.days[i] & ALARM_ENABLED)
		&& time.hour == alarm.hours[i]
		&& time.minute == alarm.minutes[i]
		&& time.second == 0
		&& (alarm.days[i] & _BV(time_dayofweek(time.year, time.month,
			    			       time.day)))) {
	    is_alarm_trigger = TRUE;
	}
    }

    // check if snooze period is over
    if((alarm.status & ALARM_SNOOZE)
	    && (++alarm.alarm_timer == alarm.snooze_time)) {
	is_alarm_trigger = TRUE;
    }

    // during sleep, briefly wake alarm to query alarm switch as necessary
    if(system.status & SYSTEM_SLEEP
	    && (is_alarm_trigger || alarm.status & ALARM_SOUNDING)) {
	alarm_wake();
	alarm_sleep();
    }

    // sound alarm if triggered and alarm switch is set
    if(is_alarm_trigger && alarm.status & ALARM_SET) {
	alarm.alarm_timer = 0;
	alarm.status &= ~ALARM_SNOOZE;
	alarm.status |= ALARM_SOUNDING;

	if(alarm.status & ALARM_SOUNDING_PULSE) {
	    display.status |= DISPLAY_PULSING;
	} else {
	    display.status &= ~DISPLAY_PULSING;
	    display_autodim();
	}

	if(system.status & SYSTEM_SLEEP) {
	    // wake user immediately to reduce alarm time,
	    // save power, and extend coin battery life
	    alarm.volume = alarm.volume_max;
	} else {
	    // set initial volume for progressive alarm
	    alarm.volume = alarm.volume_min;
	}

	piezo_setvolume(alarm.volume, 0);
	piezo_alarm_start();
    }

    // manage sounding alarm volume and timeout
    if(alarm.status & ALARM_SOUNDING) {
	// ensure display is active
	display_onbutton();

	if(alarm.volume < alarm.volume_max) {
	    // gradually increase volume (progressive alarm)
	    if(alarm.alarm_timer >= alarm.ramp_int) {
		++alarm.volume;
		alarm.alarm_timer = 0;
	    }

	    piezo_setvolume(alarm.volume,
		    	   ((uint32_t)alarm.alarm_timer << 8) / alarm.ramp_int);
	} else if(alarm.alarm_timer > ALARM_SOUNDING_TIMEOUT) {
	    // silence alarm on alarm timeout
	    alarm.status &= ~ALARM_SOUNDING;
	    display.status &= ~DISPLAY_PULSING;
	    display_autodim();
	    piezo_alarm_stop();
	}

	++alarm.alarm_timer;
    }
}


// queries alarm switch and updates alarm status
void alarm_semitick(void) {
    // update alarm status if alarm switch has changed
    static uint8_t alarm_debounce = 0;

    if(PIND & _BV(PD2)) {
	if(alarm.status & ALARM_SET) {
	    alarm_debounce = 0;
	} else {
	    if(++alarm_debounce >= ALARM_DEBOUNCE_TIME) {
		alarm.status |= ALARM_SET;
		mode_alarmset();
		display_onbutton();
	    }
	}
    } else {
	if(alarm.status & ALARM_SET) {
	    if(++alarm_debounce >= ALARM_DEBOUNCE_TIME) {
		if(alarm.status & ALARM_SOUNDING) piezo_alarm_stop();
		alarm.status &= ~ALARM_SET & ~ALARM_SOUNDING & ~ALARM_SNOOZE;
		display.status &= ~DISPLAY_PULSING;
		display_autodim();
		mode_alarmoff();
		display_onbutton();
	    }
	} else {
	    alarm_debounce = 0;
	}
    }
}
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

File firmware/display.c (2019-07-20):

// display.c  --  low-level control of VFD display
// (Display contents are controlled in mode.c)
//
//    PB5 (SCK)                      MAX6921 CLK pin
//    PB3 (MOSI)                     MAX6921 DIN pin
//    PC5*                           photoresistor pull-up
//    PC4 (ADC4)                     photoresistor voltage
//    PC3**                          MAX6921 BLANK pin
//    PC3***			     alternating current signal pin
//    PC2***			     alternating current signal pin
//    PC0                            MAX6921 LOAD pin
//    PD6                            boost transistor
//    PD3*                           vfd power transistor
//    counter/timer0                 boost (PD6) and semiticks
//    analog to digital converter    photoresistor (ADC4) voltage
//
//   * PC5 is used to directly power the photoresistor, vfd power, and
//     temperature sensor pull-up if configured for the xmas-icetube
//     hardware design.
//
//  ** PD5--not PC3--is used to control the BLANK pin if and only if
//     the IV-18 to-spec hack is enabled.
//
// *** PC3 and PC2 are used to generate an alternating current signal
//     to power the IV-18 filament if and only if the IV-18 to-spec 
//     hack is enabled.
//


#include <avr/io.h>       // for using avr register names
#include <avr/pgmspace.h> // for accessing data in program memory
#include <avr/eeprom.h>   // for accessing data in eeprom memory
#include <avr/power.h>    // for enabling/disabling chip features
#include <util/atomic.h>  // for using atomic blocks
#include <util/delay.h>   // for enabling delays


#include "display.h"
#include "usart.h"    // for debugging output
#include "system.h"   // for determining system status
#include "time.h"     // for determing current time


// extern'ed data pertaining the display
volatile display_t display;


// permanent place to store display brightness
uint8_t ee_display_status EEMEM =   DISPLAY_ANIMATED | DISPLAY_ALTNINE 
			          | DISPLAY_ALTALPHA;
uint8_t ee_display_colon_style_idx EEMEM = 0;
#ifdef AUTOMATIC_DIMMER
uint8_t ee_display_bright_min EEMEM = 0;
uint8_t ee_display_bright_max EEMEM = 6;
uint8_t ee_display_off_threshold EEMEM = 0;
#else
uint8_t ee_display_brightness EEMEM = 1;
#endif  // AUTOMATIC_DIMMER
#ifndef SEGMENT_MULTIPLEXING
uint8_t ee_display_digit_times[] EEMEM = { [0 ... DISPLAY_SIZE - 1] = 15 };
#endif  // ~SEGMENT_MULTIPLEXING

uint8_t ee_display_off_hour   EEMEM = 23 | DISPLAY_NOOFF;
uint8_t ee_display_off_minute EEMEM = 0;
uint8_t ee_display_on_hour    EEMEM = 6;
uint8_t ee_display_on_minute  EEMEM = 0;

uint8_t ee_display_off_days EEMEM = 0;
uint8_t ee_display_on_days  EEMEM = 0;


// display of letters and numbers is coded by 
// the appropriate segment flags:
#define SEG_A 0x80  //
#define SEG_B 0x40  //        AAA
#define SEG_C 0x20  //       F   B
#define SEG_D 0x10  //       F   B
#define SEG_E 0x08  //        GGG
#define SEG_F 0x04  //       E   C
#define SEG_G 0x02  //       E   C
#define SEG_H 0x01  //        DDD  H

#define DISPLAY_SPACE    0
#define DISPLAY_DOT      SEG_H
#define DISPLAY_DASH     SEG_G
#define DISPLAY_SLASH    SEG_B | SEG_G | SEG_E
#define DISPLAY_WILDCARD SEG_A | SEG_G | SEG_D

// codes for vfd letter display
const uint8_t letter_segments_ada[] PROGMEM = {
    SEG_A | SEG_B | SEG_C | SEG_D | SEG_E | SEG_G, // a
    SEG_C | SEG_D | SEG_E | SEG_F | SEG_G,         // b
    SEG_D | SEG_E | SEG_G,                         // c
    SEG_B | SEG_C | SEG_D | SEG_E | SEG_G,         // d
    SEG_A | SEG_B | SEG_D | SEG_E | SEG_F | SEG_G, // e
    SEG_A | SEG_E | SEG_F | SEG_G,                 // f
    SEG_A | SEG_B | SEG_C | SEG_D | SEG_F | SEG_G, // g
    SEG_C | SEG_E | SEG_F | SEG_G,                 // h
    SEG_B | SEG_C,                                 // i
    SEG_B | SEG_C | SEG_D | SEG_E,                 // j
    SEG_A | SEG_C | SEG_E | SEG_F | SEG_G,         // k
    SEG_D | SEG_E | SEG_F,                         // l
    SEG_A | SEG_C | SEG_E | SEG_G,                 // m
    SEG_C | SEG_E | SEG_G,                         // n
    SEG_C | SEG_D | SEG_E | SEG_G,                 // o
    SEG_A | SEG_B | SEG_E | SEG_F | SEG_G,         // p
    SEG_A | SEG_B | SEG_C | SEG_D | SEG_G,         // q
    SEG_E | SEG_G,                                 // r
    SEG_A | SEG_C | SEG_D | SEG_F | SEG_G,         // s
    SEG_D | SEG_E | SEG_F | SEG_G,                 // t
    SEG_C | SEG_D | SEG_E,                         // u
    SEG_C | SEG_D | SEG_E,                         // v
    SEG_A | SEG_C | SEG_D | SEG_E,                 // w
    SEG_B | SEG_C | SEG_E | SEG_F | SEG_G,         // x
    SEG_B | SEG_C | SEG_D | SEG_F | SEG_G,         // y
    SEG_A | SEG_B | SEG_D | SEG_E | SEG_G,         // z
};


// alternative codes for vfd letter display
const uint8_t letter_segments_alt[] PROGMEM = {
    SEG_A | SEG_B | SEG_C | SEG_E | SEG_F | SEG_G, // A
    SEG_C | SEG_D | SEG_E | SEG_F | SEG_G,         // b
    SEG_A | SEG_D | SEG_E | SEG_F,                 // C
    SEG_B | SEG_C | SEG_D | SEG_E | SEG_G,         // d
    SEG_A | SEG_D | SEG_E | SEG_F | SEG_G,         // E
    SEG_A | SEG_E | SEG_F | SEG_G,                 // F
    SEG_A | SEG_C | SEG_D | SEG_E | SEG_F,         // G
    SEG_B | SEG_C | SEG_E | SEG_F | SEG_G,         // H
    SEG_B | SEG_C,                                 // I
    SEG_B | SEG_C | SEG_D | SEG_E,                 // J
    SEG_A | SEG_C | SEG_E | SEG_F | SEG_G,         // K
    SEG_D | SEG_E | SEG_F,                         // L
    SEG_A | SEG_C | SEG_E | SEG_G,                 // M
    SEG_C | SEG_E | SEG_G,                         // n
    SEG_A | SEG_B | SEG_C | SEG_D | SEG_E | SEG_F, // O
    SEG_A | SEG_B | SEG_E | SEG_F | SEG_G,         // P
    SEG_A | SEG_B | SEG_C | SEG_D | SEG_G,         // q
    SEG_E | SEG_G,                                 // r
    SEG_A | SEG_C | SEG_D | SEG_F | SEG_G,         // S
    SEG_D | SEG_E | SEG_F | SEG_G,                 // t
    SEG_B | SEG_C | SEG_D | SEG_E | SEG_F,         // U
    SEG_B | SEG_C | SEG_D | SEG_E | SEG_F,         // V
    SEG_A | SEG_C | SEG_D | SEG_E,                 // W
    SEG_B | SEG_C | SEG_E | SEG_F | SEG_G,         // X
    SEG_B | SEG_C | SEG_D | SEG_F | SEG_G,         // y
    SEG_A | SEG_B | SEG_D | SEG_E | SEG_G,         // Z
};


const uint8_t number_segments[] PROGMEM = {
    SEG_A | SEG_B | SEG_C | SEG_D | SEG_E | SEG_F,         // 0
    SEG_B | SEG_C,                                         // 1
    SEG_A | SEG_B | SEG_D | SEG_E | SEG_G,                 // 2
    SEG_A | SEG_B | SEG_C | SEG_D | SEG_G,                 // 3
    SEG_B | SEG_C | SEG_F | SEG_G,                         // 4
    SEG_A | SEG_C | SEG_D | SEG_F | SEG_G,                 // 5
    SEG_A | SEG_C | SEG_D | SEG_E | SEG_F | SEG_G,         // 6
    SEG_A | SEG_B | SEG_C,                                 // 7
    SEG_A | SEG_B | SEG_C | SEG_D | SEG_E | SEG_F | SEG_G, // 8
    SEG_A | SEG_B | SEG_C | SEG_F | SEG_G,                 // 9
};
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

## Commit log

2012-11-06 Alarm works during sleep mode
    If the alarm switch is set, the alarm will go off in sleep
    mode. Snooze does not work and the alarm is turned off by
    flipping the alarm switch. Since the display is inactive
    there is no snooze indicator anyway.
    [alarm.c, display.c]
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2012-11-07 Improved alarm, date, and time displays
    Before setting the time, the clock prompts for a selection between
    "24-hour" and "12-hour". Before setting the date, the clock prompts
    for a selection between "dd-mm-yy" (EU format) and "mm-dd-yy"
    (US format).
    While the clock is displaying the time, the user may see the current
    day of week, month, and day of month by pressing the set or plus
    buttons (like the original Adafruit firmware).
    If in the time display mode, the clock displays an alarm status
    message when the alarm is turned on and off (like the original
    Adafruit firmware).
    The display_string("...") function has been removed and replaced by
    display_pstr(PSTR("...")), which uses program memo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
    [alarm.c, display.c, display.h]
2012-11-07 Pins optimized for clock sleep
    The unconnected pins now have pullups enabled, and the button and
    alarm switch pins are clamped to ground during sleep. The sleep
    switch might be shorted to ground and, if the clock is tightly packed
    in a suitcase, so might the buttons. So for the button and alarm
    switch pins, clamping to ground seems preferable to enabling pull-up
    resistors. The remain pins have been similarly optimized while in
    sleep mode.
    Oddly enough, I do not observe any power savings as a result of these
    efforts! Oh well... I suppose doing the theoretically right thing is
    worth committing, as long as the changes do no harm.
    [alarm.c, button.c, display.c]
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2012-11-10 Enhanced alarm features
    Snooze is now adjustable and volume can slowly increase while the
    alarm sounds.
    After a system reset, the clock now shows the reason for the reset
    until time is set.
    [alarm.c]
2012-11-15 Support for automatic drift correction
    The code for automatic drift correction might work has been added, but
    still needs some serious testing to ensure functionality.
    Also added is usart.c and usart.h for handling serial communication
    for GPS, debugging, and whatever else.
    [display.h]
2012-11-16 Added user-control of progressive alarm duration
    The duration of the progressive alarm can be set from 1 to 30 minutes.
    Many chunks of time manipulations code are now in atomic blocks to
    prevent rare race conditions which would cause incorrect timekeeping.
    [alarm.c]
2012-11-16 Sleep bug workaround
    If the system is powered-on using the battery, sleep never woke. This
    seems to be a hardware problem with my atmega128v, but inserting a
    100ms delay before sleep seems to fix the problem.
    [display.c]
2012-11-19 Added autodim support
    With a photoresistor and 10K pull-up installed in the expansion holes
    of an Ice Tube Clock, display brightness can be automatically
    controlled by ambient light.
    Because I blew my atmega128v, I'm running on an atmega328p. Sleep now
    seems to work intermittently, and I do not know if this is do to the
    hardware change, this update, or is just something I never noticed
    before.
    [display.c, display.h]
2012-11-19 Hardware sleep bug work-around
    The problem with sleep for the previous commit was that the analog to
    digital converter was not being disabled by power_adc_disable(). The
    workaround was to disable ADC through the ADC configuration register.
    [display.c]
2012-12-01 Alarm can play music!
    The music and buzzer control code is now in pizo.{c,h} and not in
    alarm.{c,h}. Only one song is implemented---"We Wish You a Merry
    Christmas"---but more may follow.
    Two sleep bugs have also been squashed.
    [alarm.c, buttons.c, display.c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]
2012-12-01 Minor tweaks
    Extended watchdog timer to eight seconds, removed incorrect comment
    regarding timer2, changed program memory pointer definition for
    backwards compatibility with avr-gcc 4.5.3, and no longer disable
    any timers in PRR.
    [display.c, system.c]
2012-12-03 Documentation edits, minor sleep bug fixed
    The README now contains (rather minimal) installation instructions.
    If the alarm buzzer was turned off while the pizo element was emitting
    sound, sleep would be inefficient until the alarm buzzer sounded
    again. For a brief power failure, this bug would pose no problem, but
    a longer failure (many hours) would likely drain the backup battery
    completely... This problem has been fixed.
    [display.c, display.h, pizo.c]
2012-12-08 Per-digit brightness control + bugfixes
    Since some tubes have dimmer digits to the right, the firmware now
    includes per-digit brightness controls under "set digit."
    This commit also includes two drift correction bugfixes.
    The the first sometimes caused the clock to stop calculating drift
    correction values after the user set the current time. Normal
    behavior would resume after a system reset.
    The second caused drift correction values to be incorrectly calculated
    in most cases. I think the long-term timekeeping would still been
    better than with an uncorrected time, but not as good as the
    timekeeping could be.
    [display.c, display.h, pizo.c]
2012-12-10 Brightness control improvements
    The per digit brightness control no longer flickers. Before the
    per-digit brightness control would flicker when a user increased
    around 1/2 of the digits to maximum brightness---not a typical usage
    scenario but might happen nonetheless.
    The autodim minimum and maximum values may now range from -5 to
    20---beyond the allowed brightness range of 0 to 10. The actual
    display brightness, however, will never be brighter or dimmer than
    allowed to ensure that the display will always be visible and prevent
    display damage.
    With the autodim feature, display brightness is calculated from
    photoresistor voltage. In the dark, voltage is highest and decreases
    as the ambie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
    [display.c, display.h]
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2012-12-22 Alarm settings no longer forgotten when disabled
    Before, if an alarm was disabled, the days-of-week in which the alarm
    was to sound was forgotten. Now, each alarm remembers all previous
    settings when disabled and later enabled.
    Also a minor date display bug has been fixed.
    [alarm.c, display.c]
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2012-12-30 Improved Adafruit-style buttons
    The compile-time option for Adafruit-style buttons is now in the
    Makefile (config.h no longer exists), and this option is now enabled
    by default. Although the new button scheme is more logical, anyone
    trying this firmware will already be familiar with the old Adafruit
    scheme, so I think it makes more sense to use that as the default.
    Defining the "ADAFRUIT_BUTTONS" macros also disables the circular
    menus for a more Adafruit-style behavior. In other words, continually
    pressing menu while in the menus will eventually move to the
    time-display screen.
    [display.c]
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2013-01-22 Added Maxim DS32kHz support
    As described in the Adafruit Clocks forum, the Maxim DS32kHz may be
    used with the Ice Tube Clock to increase the accuracy of timekeeping.
    http://forums.adafruit.com/viewtopic.php?f=41&t=14941
    This feature may be enabled by defining the EXTERNAL_CLOCK macro in
    config.h. Doing so, allows the ATmega328p to accept an external clock
    signal on XTAL1 instead of the usual crystal oscillator. Also,
    defining this macro raises the BOD threshold voltage from 1.8 to 2.7,
    because the DS32kHz requires 2.7 volts for timekeeping.
    I also moved the ADAFRUIT_BUTTONS macro from the Makefile to config.h,
    where future compile-time options belong.
    Finally, the Makefile no longer de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
    [display.h, system.h]
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2013-02-06 Configuration menu reorganization
    Eventually, I'd like to add support for multiple date and time
    formats, as well as a temperature display in Celsius or Fahrenheit,
    But these options do not fit under any of the "cfg" submenus. So the
    "cfg time" submenu is now labeled "cfg regn" (configure region).
    Some day, "cfg regn" will contain additional options for date format,
    time format, and temperature units ("date fmt", "time fmt", and
    "set °C.°F").
    This release also includes new configuration options in config.h:
    GPS timekeeping, automatic dimmer, display voltage range, and USART
    baud rate. Most notably, firmware support for hardware hacks may now
    be enabled and disabled at compile time.
    [display.c, display.h]
2013-02-08 Display transition bugfix
    A minor visual artifact during the scroll left animated transition has
    been fixed.
    [display.c]
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2013-02-14 New display options and adjustments
    Under "cfg regn"/"digt fmt", users may select between adjusted numbers
    and zero-padded numbers and between representations of nine.
    A new GPS-lock indicator may be displayed when the AM/PM indicator is
    unneeded or the DST status is hidden.
    There is an new experimental display-gradient correction included
    under "cfg disp"/"digt bri".
    The Adafruit Ultimate GPS seems to output an incorrect NMEA RMC record
    immediately after turning on. This caused the clock to start with an
    incorrect time after waking sleep. The GPS time code now disregards
    the first good NMEA RMC record, and sets time after parsing the second
    good record.
    [display.c, display.h]
2013-02-18 Subsecond time-setting accuracy
    When a user sets the time, the fractional seconds are reset to zero.
    For example, setting the clock to "16 30 00" now sets the clock to
    16:30:00.00. This change is meant to make it possible to manually
    synchronize the Ice Tube Clock with an accurate time source with
    subsecond accuracy.
    Although this seems like a trivial modification, tracking fractional
    seconds in the drift correction code is fraught with race conditions
    and asynchronous timer management subtleties. I think I've done
    everything correctly, but time will tell. ;-)
    Another change is that the GPS code only synchronizes time after the
    clock time has drifted by more than one full second. Befor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
    [alarm.c]
2013-02-19 Display update efficiency improvements
    Display updates happen often--every ~500 microseconds, by default.
    During these updates, interrupts must be suspended to prevent display
    flicker. New display update efficiency improvements allow interrupts
    to be handled in a more timely fashion.
    [display.c, display.h]
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2013-02-20 Auto-off bugfix
    "Off time" was always enabled, even if disabled through the menus.
    This has been fixed.
    [display.c]
2013-02-22 Finer control of per-digit brightness
    The per-digit brightness controls ("cfg disp"/ "digt bri"), now
    provide much finer control. With the finer control, the experimental
    brightness gradient correction is not necessary and has been removed.
    The "date fmt" and "time fmt" entries are now in reverse order to
    match the order of "set time" and "set date". This also puts
    "time fmt" next the other time controls, "set dst " and "set zone".
    The README and CREDITS files have been updated to reflect new
    features. The new auto-off feature is now better commented in the
    source code.
    [display.c, display.h]
2013-02-22 Improved piezo control
    The code to control volume of lower frequencies now exploits the piezo
    element's resonant frequency to set volume. The effect is to maximize
    sound pressure at the highest volume level.
    More careful control of Timer/Counter 1 when generating frequencies
    has eliminated the faint clicking noise at low volume.
    [pizo.c]
2013-02-23 Display pulse bugfix
    If the firmware was compiled without automatic dimmer support, the
    display-pulsation-on-alarm (if enabled) would fail to restore the
    display to its normal brightness. This has been fixed.
    [alarm.c]
2013-02-24 Corrected piezo spelling
    In the source code, the spelling of piezo has been changed from "pizo"
    to the longer but more correct "piezo."
    The program has not changed, just the names of some constants,
    variables, and functions.
    [alarm.c, buttons.c, piezo.c]
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2013-03-03 Additional alarms & improved piezo control
    The "beeps" alarm has been renamed to "beeps hi" and there is now a
    "beeps lo" which provides a lower frequency, and less annoying,
    beeps-style alarm.
    The new alarms called "pulse hi" and "pulse lo" provide another
    traditional alarm style, the three beep pulse, with both low and high
    frequency beep pulses.
    For birthdays and congratulatory occasions there is a new musical
    alarm: "For He's a Jolly Good Fellow".
    A minor progressive alarm bugfix allows for smoother transitions from
    low to high volume.
    The alarm indicator (0th-digit "-") now blinks while the alarm is
    sounding and while snoozing.
    Code, comment, and documentation edits make things mo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
    [alarm.c, piezo.c]
2013-03-13 Minor bugfixes; Dragon compatibility; updated docs
    An alarm volume of 10 saved to EEPROM would be restored as a volume
    of 0! This only happened after a microcontroller reset which only
    happens if the clock battery is absent or dead. This has been fixed.
    The controls in config.h to compensate for phosphor loss in an aging
    VFD tube did not work at all! This has been fixed.
    The Makefile has been modified to allow compatibility with the
    Atmel AVR Dragon programmer.
    The default alarm volume is now a progressive alarm from volume 0 to
    volume 10 over a 1 minute period.
    Documentation in the README and config.h has been updated.
    [alarm.c, display.c]
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2013-06-04 Extended battery hack deprecated
    After the previous commit, power used by an Ice Tube Clock in the
    without any hardware modification was 10.6 uA.
    To make the clock more efficient, I tried cutting the trace between
    the resistor divider and system power, instead connecting the resistor
    divider directly to the voltage divider. This setups is just like the
    extended battery hack except there is no second wire soldered between
    the voltage regulator and PC1. After that change current at 3.3v fell
    to 1.5 uA--better than the extended battery hack!
    So there is no longer a need for a software component of the extended
    battery hack. The PC1 is tri-stated so future versions of this
    firmware will be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
    [system.c]
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2013-07-20 Aging display compensation with autodimmer bugfix
    The boost configuration settings can be increased in config.h to
    compensate for an aging VFD display with fading phosphors. Doing so,
    however, could cause automatic dimming to behave erratically. This
    bug has been fixed.
    [display.c]
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2013-08-02 Alarm during sleep and non-beep alarm bugfix
    This firmware allows the alarm to sound, even while on battery power.
    But if the alarm sound was set to the three-beep pulse or one of the
    musical alarms, the alarms would not sound when external power was
    lost. This has been fixed.
    [piezo.c]
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2013-10-05 Added xmas-icetube hardware redesign
    The xmas-icetube project now includes an alternative circuit board and
    case design in addition to the xmas-icetube firmware.
    [icetube.brd, icetube.sch]
2013-10-05 Revised the xmas-icetube board
    This commit updates the Ice Tube Clock board to revision C. Although
    revision C is untested, the circuit is identical to revision B, so I
    cannot imagine that there would be any problems.
    [mainpcb.brd, mainpcb.sch, sidepcb.brd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]
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2013-10-21 Revised xmas-icetube board (Rev. D)
    The xmas-icetube (Rev D) board is currently *untested*, so use this
    design at your own risk. Rev. D includes an enhancement to the
    filament driver circuit to increase filament voltage to within
    specifications. The filament voltage issue has been discussed in the
    Adafruit Clocks forum:
    http://forums.adafruit.com/viewtopic.php?p=223798#p223798
    http://forums.adafruit.com/viewtopic.php?p=223793#p223793
    [mainpcb.brd, mainpcb.sch]
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2013-11-03 Corrected C6 value in board schematic
    In both the Ice Tube Clock kit and the xmas-icetube revisions, C6 is
    22uF but was marked as 33uF in the schematic. This has been fixed.
    [mainpcb.brd, mainpcb.sch]
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2013-11-14 Added options to fine-tune IV-18 driver
    There are now three multiplexing algorithms (digit multiplexing,
    subdigit multiplexing, and segment multiplexing) to choose from
    at compile-time; see the comments in config.h for details.
    With the IV-18 to-spec hack, display brightness may now be controlled
    with boost voltage, pulse width modulation, or both simultaneously;
    see config.h for details.
    Finally, this commit includes a workaround to reduce/eliminate display
    flicker during queries to the DS18B20 temperature sensor for clocks
    with software temperature compensated timekeeping.
    [display.c, display.h, temp.c]
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2013-11-19 Corrected error in BOM (thanks Phil!)
    Phil DeGruy noticed that the R4 part numbers in the bill of materials
    was incorrect. This has been fixed.
    [BOM.csv]
2013-11-20 Autodim bugfix (thanks Phil!)
    Phil DeGruy noticed that the autodimming didn't work under certain
    circumstances. It seems I introduced this bug when rewriting code to
    support alternative ways to drive the IV-18. Oops!
    This bug has been fixed.
    [display.c]
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2013-11-21 Changes to BOM (thanks Phil!)
    Phil DeGruy found several parts which were less expensive than the
    existing parts.
    Also, I noticed that C6 gets a bit warm, being close to the LM317
    voltage regulator. So I replaced C6 with a better cap (33uF, 100v,
    2000h@105degC). The larger capacitance will reduce boost ripple and
    the higher temperature rating will ensure longer life.
    [BOM.csv]
2013-11-21 Autodimming control improvement
    With the autodimming mod, the clock has 80 brightness levels. Ambient
    lighting is measured by the photoresistor and converted to a number in
    the range [0, 80]. When ambient brightness is "between" two levels of
    display brightness, the display can flip back and forth between
    brightness levels. Occasionally this can result in visible flicker.
    Display brightness now lags behind ambient brightness by one level,
    which should eliminate the flickering effect.
    [display.c, display.h]
2013-11-23 Sleep code more robust against crystal problems
    If the crystal oscillator is nonfunctional, the system will sleep, but
    never wake for the once-per-second interrupt. This could make
    debugging a bad crystal oscillator difficult, because the system would
    seem to be dead. Furthermore, because the sleep code is extremely
    power efficient, the system can run off power stored in the capacitor
    for minutes, so removing the battery and external power will not reset
    the system right away. And if clock power is stored before the
    capacitors are drained, the clock will appear to be dead.
    To address the issue, the watchdog timer now remains on for the first
    five seconds. After waking five times (once p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
    [system.c, system.h]
2013-11-24 Improved initial default settings
    The default time format, date format, timezone offset, and DST
    settings now default to the computer on which you compile this
    firmware. Also automatic dimming is enabled by default, if that when
    that feature is available. Display pulsing during alarm and snooze is
    now also enabled by default.
    This commit also fixes a bug which caused the automatic fall DST
    correction in the European Union to happen an hour ahead of schedule.
    [alarm.c, display.c]
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2013-11-30 Minor hardware documentation updates
    The hardware/README file now describes the correct orientation of Q2,
    and made a few substitutions in the bill of materials.
    [BOM.csv]
2013-12-03 Enhanced filament driver options
    The config.h file now includes macros to lower the frequency of the
    filament drive as well as macros to run the filament under DC in both
    the forward and reverse directions.
    [display.c, display.h]
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2014-01-07 Updated documentation, changed defaults
    The USAGE describes more details in setting the time, date, and
    miscellaneous format options in the configuration menus.
    The README file now describes how to use the new "verify" targets in
    the Makefile.
    The option under "cfg regn"/"cfg dst" for Western European Time is now
    called "WET" instead of "GMT", because strictly speaking, GMT does not
    include daylight saving time.
    The automatic dimmer and GPS support compile-time options do not cause
    problems if they are enabled without the corresponding hardware mods,
    so these options are now enabled by default in config.h.
    Several of the menu-configurable option defaults are different as
    well. The defau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
    [display.c, piezo.c]
2014-01-13 External TCXO & sleep bugfix
    With an external clock such as the DS32kHz TCXO, voltage would not
    stabilize sufficiently for the repeated analog-to-digital measurements
    of battery voltage during sleep to converge. As a result, the
    analog-to-digital converter would run continuously and drain the
    battery in a short amount of time--around thirty minutes.
    To resolve the issue, the voltage measurement algorithm now uses a
    looser criteria for convergence and enforces a maximum number of
    analog-to-digital conversions.
    [system.c]
2014-01-24 Minor documentation updates in code and docs
    The documentation incorporates loads of minor revisions--almost
    exclusively typographical and grammatical corrections and revisions.
    In the code, the tunable parameters for low battery detection are now
    documented with comments and have been moved from system.c to
    system.h.
    [system.c, system.h]
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2014-02-24 Sleep race condition bugfix
    Due to a race condition in the sleep code, the VFD filament could
    sometimes be left on when the clock goes to sleep. This bug should
    only effect clocks with the IV-18 to-spec hack.
    [display.c]
2014-03-20 Minor DST bug and possible sleep bug fixed
    Automatic DST state changes now get saved to EEPROM, so they are
    correctly restored after the clock resets. (The clock should only
    reset when the power goes out and the backup battery is dead.) Since
    people expect that time might be wrong when the clock resets, this
    bug was never really problematic.
    Also, I noticed that interrupts are enabled during the piezo_sleep()
    function. None of the sleep functions should enable interrupts, as
    doing so might make race conditions possible. I'm not sure if
    enabling interrupts at this point could have actually caused any
    problems, but the code has been changed to function as intended.
    [piezo.c, system.c, system.h]
2014-04-02 Temperature sensor errors are now displayed
    If the TEMPERATURE_SENSOR macro is enabled in config.h, the clock will
    use an attached DS18B20 temperature sensor to perform software
    temperature compensation.
    But if communication with the sensor failed, the clock would appear to
    function normally--except that no temperature compensation would be
    performed. Now, the clock will periodically display a "temp err"
    message to show the communication failure.
    The absence of the "temp err" message will now provide assurance that
    the clock is communicating with the DS18B20 and that temperature
    compensation is being performed.
    [system.c, system.h]
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
